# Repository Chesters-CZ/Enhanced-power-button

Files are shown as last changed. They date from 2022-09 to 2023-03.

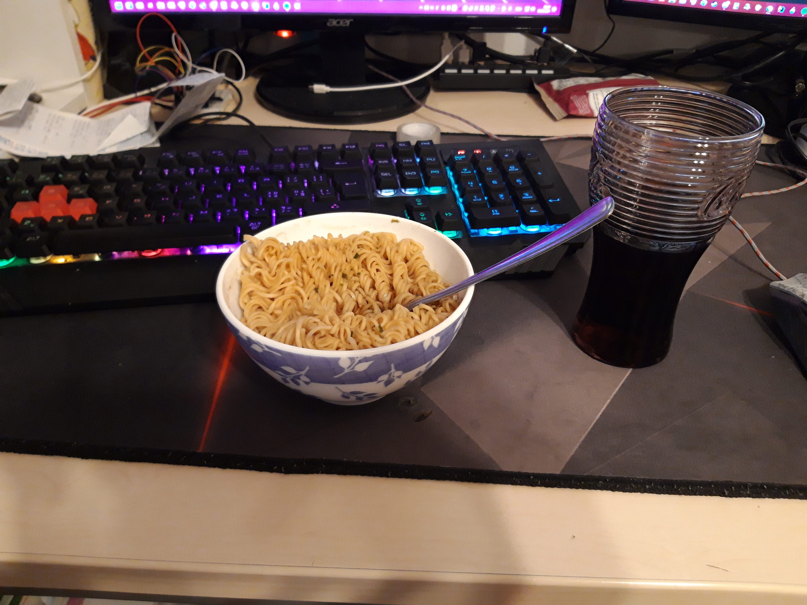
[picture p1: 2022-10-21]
fotky a schémata/concept art/20211015_182709 (1).jpg

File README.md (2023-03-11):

## Enhanced-power-button

Have you ever noticed how boring starting your computer is? You just press a button and that's it, but don't worry. I'm here to help!

# Introducing the triple Arduino setup



*this is an old picture, the final build is still a work-in-progress*

### The main Arduino

The main Arduino is the screen module. It turns on the PC via a long cable connected to the motherboard's `PWR+` and `PWR-` pins. This is triggered by the user pressing a button. The two secondary Arduinos are connected to this one, so that the screen can display popups depending on the current status of the setup. It also communicates with the python script on the computer.

### The audio module

The first secondary Arduino is the audio module. This one plays a random audio file from the connected micro SD card when the PC is turned on. If there's an error during initialization, it transmits the error code via morse code through the speaker. 

### The keycard modules

The third Arduino reads an encrypted string from a MIFARE keycard, which is decrypted using a key hardcoded on the Arduino. The decrypted string is then sent to the computer as keyboard input localized for the default Czech QWERTZ keyboard layout. If the user has chosen so when writing to the keycard, the arduino can lock the connected PC using the `Win+L` button combo. 
There is also an uploader version, which encrypts a set string and writes it onto keycards. The user chooses whether to lock the PC on removal before writing to each of the keycards.

### The python script

This is a script designed to be run on OS startup. On Windows, this can be accomplished by creating a shortcut to the .py file in `C:\Users\YourName\AppData\Roaming\Microsoft\Windows\Start Menu\Programs\Startup`. It contacts all of the Arduinos through their respective COM ports, restarting them in the process. The script then loads a config file from the user's folder in `C:\Users\` and tells the main Arduino what to display when idle. If the user has chosen time or date to be displayed, the script also sends the current time and possibly the date. The Arduino is not able to keep time information through a reboot, only keeping track of how long it is running and even that deviates by around -120s per 24h. By refreshing the time information every time the computer is rebooted, I can ignore dealing with leap years and daylight savings time by just making the user restart their computer or relaunch the script.

#### NOTE: If you're getting an error about a missing Serial module, run `pip install pyserial`. The library I used for serial communication is not installed by default.

#### NOTE 2: I could only upload a compressed version of the final pdf. The original version is available on my website [here](https://chesters.cz/files/Maturitni-prace.pdf).

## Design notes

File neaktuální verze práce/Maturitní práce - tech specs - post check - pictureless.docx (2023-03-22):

MATURITNÍ PRÁCE

Obohacené zapínací tlačítko se zabezpečovací funkcionalitou

Studijní obor: IT

Třída: C4

Školní rok: 2022/2023

Jméno a příjmení: Vít Bezouška

Vedoucí práce: Radek Lampíř

Abstrakt

Popis zařízení zlepšující požitek ze zapínání stolního počítače. Nabízí základní zabezpečovací funkce a možnosti přizpůsobení.

Abstract

Describing a device used to enhance the user experience of turning on one’s PC. Some basic security and customization features are included.

Klíčová slova

Arduino, hardware, periferie, C++, elektronika

Prohlašuji, že jsem tuto práci vypracoval(a) samostatně a použil(a) jsem literární prameny a informace, které cituji a uvádím v seznamu použité literatury a zdrojů informací.

V Praze dne …………. ……..……………………

jméno a příjmení

Obsah

Úvod 8

Účel zařízení 9

Ochrana zapnutí počítače 9

Ochrana před fyzickými keyloggery 9

Automatické uzamčení počítače při odchodu 10

Způsob, jak zapnout počítač bez sehnutí 10

Zpříjemnění začátku pracovní doby 10

Zobrazení času nebo data 10

Limitace zařízení 11

Zapínání počítače nelze zabezpečit 11

Heslo na RFID čipu lze přepsat 11

Přeprogramovatelnost Arduin 11

Použité materiály 12

Popis jednotlivých součástek 13

Arduino Nano 13

Jak se s Arduinem pracuje? 13

Co je COM port? 13

Arduino Leonardo 14

Breadboardy 15

Jednopinové spoje 15

LCD displej 15

Reproduktor 16

Červené tlačítko s krytkou 16

Páčkový přepínač 16

Čtečka micro SD karet a karta samotná 16

PNP tranzistor 17

680KΩ rezistor 17

Drát do počítače a zpět 17

Spínač na zámek 17

LED diody 17

RFID-RC522 a MIFARE čip 18

Dvojitý terminál 18

Malé šroubky 18

Použitý software 19

Word 19

Arduino IDE 19

Programování Arduin v Arduino IDE 19

PyCharm Professional 23

GIMP 23

image2cpp 23

Audacity 24

GitHub 24

FontConvert 24

Tinkercad 25

Draw.io 25

Použité knihovny 26

Adafruit GFX a SSD1306 26

TMRpcm 26

SpaniakosAES 26

Implementace base64 26

CzechKeyboard 26

Easy MFRC522 26

Popis jednotlivých modulů 27

Obrazovkový modul 27

Popis fungování 27

setup() 27

loop() 28

Uživatel nemačká tlačítko 28

Uživatel mačká tlačítko 28

Audio modul je připraven 29

Audio modul není připraven 29

Audio modul 29

Popis fungování 29

setup() 29

loop() 30

RFID moduly 30

Zapisovací (šifrovací) modul 30

Popis fungování 31

setup() 31

loop() 31

Čtecí (dešifrovací) modul 32

Popis fungování 32

setup() 32

loop() 32

Šasí 34

Základ krabičky 34

Stropní panel 35

Boční panel 35

Závěr 36

Seznam použitých zdrojů 37

Slovník pojmů 38

# Úvod

Tato práce popisuje mnou navržené a vytvořené zabezpečovací zařízení pro stolní počítač a jeho vlastnosti.

Funkcionalita je rozdělená mezi tři mikrokontrolery Arduino, konkrétně dva modely Nano a jeden model Leonardo. Jedno Nano ovládá displej, zapíná počítač a komunikuje s pythonovým scriptem. Toto Nano a k němu připojené periferie budu nazývat displejovým nebo obrazovkovým modulem. Druhé z Nan na povel displejového modulu přečte z micro SD karty audio soubor a přehraje ho. Nazývejme jej zvukovým modulem. Úkolem Arduina Leonardo je přečíst zašifrované heslo z přiloženého RFID čipu nebo karty, dešifrovat ho, a následně ho poslat jako klávesnicový vstup do počítače. To je modul čipový.

Zabezpečení samotné je zajišťováno třemi funkcemi. Zařízení zaprvé omezuje přístup k napájecímu tlačítku počítače nepovolaným osobám tak, aby nemohly počítač vypnout ani zapnout. Zadruhé pracuje jako password manager hesel uložených na RFID čipu či kartě. Poslední funkcí je možnost nastavení automatického odhlášení z uživatelského profilu v systému Windows po odejmutí čipu či karty ze čtecího senzoru.

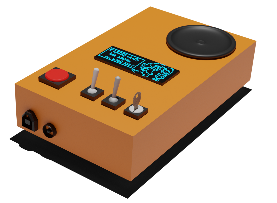
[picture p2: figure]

Součástí práce bylo navrhování a sestavování hardwarových obvodů, navrhování 3D tištěného šasí, programování mikrokontrolerů Arduino v C++ a vytváření pythonového scriptu, který zprostředkovává komunikaci mezi počítačem a jedním z Arduin.

SEQ Obrázek \* ARABIC 1 První vizualizace toho, jak by mohla vypadat finální podoba zařízení

# Účel zařízení

Hlavním cílem tohoto modulu je pomoct i laickému uživateli zabezpečit jeho počítač před těmi nejobecnějšími kyberhrozbami a navíc trochu zpříjemnit jeho používání.

## Ochrana zapnutí počítače

Spínač na klíč funguje jako prevence neoprávněného zapnutí. Tento způsob ochrany je sice velmi jednoduchý, ale nelze ho obejít, aniž by byly zanechány známky vniknutí. Stačí na šroubky na krabičce a od počítače nalepit bezpečnostní nálepky. Když se uživatel vrátí k počítači a uvidí, že se do něj někdo pokoušel dostat, může si okamžitě změnit hesla a zabránit tak neoprávněnému přístupu do svých účtů.

SEQ Obrázek \* ARABIC 2 Příklad použití bezpečnostní nálepky k zabezpečení krabičky čokoládových bonbónů

## Ochrana před fyzickými keyloggery

Keylogger je zařízení, které si zapamatovává uživatelské vstupy aniž by je blokovalo a je schopno je poté poskytnout útočníkovi, který z nich může vyčíst citlivé údaje. Proti digitálním keyloggerům se lze bránit pomocí aktuálního antivirového programu. Existují ale také fyzické keyloggery, malá zařízení se dvěma USB porty. Do jednoho se připojí zařízení, které bude odposloucháváno a ten druhý se připojí do počítače. Zařízení si všechny vstupy ukládá do interního úložiště, nebo je přeposílá dál přes wifi.[1]

Přestože průměrný keylogger stojí okolo 1500Kč, začínají se s nimi setkávat i učitelé na základních školách. Dají se totiž objednat na dobírku přes internet. Děti jimi pak získávají přihlašovací údaje učitelů, které následně zneužívají.[2] Správné použití mého zařízení tohle může přinejmenším velmi ztížit.

Používá totiž čtečku MIFARE RFID karet, ze kterých přečte zašifrované heslo, sám si ho dešifruje a výsledek pošle do počítače jako klávesnicový vstup. Je tedy také zranitelný vůči tomuto útoku. Když se ale zkombinují tyto dva způsoby zadávání hesla, může to útočníkovi ztížit získávání hesla. Například když klávesnicí uživatel zadá hes, mým modulem lo, a klávesnicí ještě 123, útočníkovi se zobrazí hes123 a lo odděleně a bude pro něj těžší získat tu správnou kombinaci.

## Automatické uzamčení počítače při odchodu

Na čipovou kartu, na které je uložené zašifrované heslo, lze také nahrát informaci o tom, zda má RFID modul po odebrání karty ze čtečky zamknout počítač. Kdyby se pak čipová karta používala i třeba k odemknutí dveří toalety, musel by si ji uživatel vzít s sebou, a jeho počítač by pak nezůstal odemčený a zneužitelný.

## Způsob, jak zapnout počítač bez sehnutí

Umístí-li si uživatel modul na stůl, nebude se muset shýbat k zemi, aby si zapnul počítač.

## Zpříjemnění začátku pracovní doby

Modul po spuštění počítače přehraje náhodný zvuk z připojené micro SD karty. Uživatel si na ní může nahrát své oblíbené písničky a zlepšit si náladu ještě než se pustí do práce.

## Zobrazení času nebo data

Podle toho, co si uživatel zvolí, se na displeji může při nečinnosti zobrazovat buď aktuální datum, nebo čas. Nastavení data a času se aktualizuje na systémové hodnoty při každém spuštění počítače, není tedy třeba modul přenastavovat každých půl roku.

# Limitace zařízení

Toto zařízení není perfektní a má jisté nedostatky. Považujme ho za proof of concept, ne jako finální produkt. Mnoho těchto chyb je totiž způsobeno limitacemi, které není realistické řešit v mém socioekonomickém postavení.

## Zapínání počítače nelze zabezpečit

Dokud se budou počítače zapínat pomocí zkratování dvou pinů, nebude možné jej efektivně ochránit před neoprávněnými osobami. Vždy totiž bude možné nějakým způsobem obnažit kontakty a zkratovat je.

Tohle by se dalo vyřešit spoluprací s výrobci základních desek. Kdyby totiž základní deska reagovala pouze na zaslání nějakého relativně unikátního kódu, šlo by moje zařízení vybavit zabezpečovacím čipem, který by se základní deskou komunikoval a takovýto kód poskytl.

Mohlo by se jednat o hardwarový bezpečnostní token, který by si se zapnutým počítačem vyměňoval seedy ke generování klíčů. Vypnutý počítač by pak požadoval kód, který by hardwarový token vygeneroval třeba z několika posledních seedů a aktuálního času. Útočník by potom neměl jak počítač zapnout.

## Heslo na RFID čipu lze přepsat

Jelikož jsou data zapsaná na čipy, užívané v tomto projektu, přepsatelná, útočník by je teoreticky mohl změnit anebo smazat. Ideálně by se používaly čipy s pamětí WORM. Při změně hesla nebo šifrovacího klíče by pak ale bylo nutné vydat uživateli nový čip.

## Přeprogramovatelnost Arduin

Mikrokontrolery, které používám jsou jednoduše přeprogramovatelné. Stačí je připojit k počítači a nahrát do nich jiný kód. Tento nedostatek by se dal vyřešit využitím vlastních designů mikrokontrolerů s WORM pamětí.

# Použité materiály

Na každý projekt je potřeba trocha hardwaru. Zde je seznam toho, co bylo použito na tento projekt.

Počet | Součástka
2 | Arduino Nano
1 | Arduino Leonardo
1 | Breadboard malý
2 | Breadboard velký
>50 | Jednopinový spoj
1 | IIC LCD displej 128x32px, jednobarevný
1 | Reproduktor 2W 8Ω
1 | Velké červené tlačítko
1 | Odklápěcí kryt na velké červené tlačítko
3 | Páčkový přepínač
1 | Micro SD modul
1 | Micro SD karta
4 | PNP tranzistor
1 | Malý 680kΩ rezistor
2 | Kabel, který dosáhne od krabičky k PW pinům
1 | Spínač na zámek (s klíčkem)
4 | Libovolná LED dioda
1 | RFID modul RC-522
1 | MIFARE Classic čip
1 | Šroubovací terminál na dva drátky
12 | Šroubků 2x10mm

# Popis jednotlivých součástek

Důležité je vědět nejen co použít, ale i jak to použít.

## Arduino Nano

Nejstarší model Arduina, který se dnes běžně používá. Arduino je vlastně jen veřejně dostupná technická specifikace, podle které si kdokoliv může nechat vytvořit své vlastní Arduino. Arduina, která já používám v tomto projektu nejsou originální, jde o verzi z Číny za zlomek ceny. Pořád ale mají naprosto identickou funkcionalitu jako kdybych si koupil originální Genuino, a protože se prodejce nesnažil tvrdit, že by šlo o oficiální výrobek, je toto Arduino naprosto legální.[3]

SEQ Obrázek \* ARABIC 3 Arduino Nano

Arduino Nano v sobě má mikrokontroler ATmega328 o frekvenci 16 MHz a samo o sobě spotřebovává zhruba 20 mA při 5V DC. Tato spotřeba se samozřejmě zvyšuje, když k němu připojíme nějakou periferii. Každý z jeho 22 I/O pinů totiž dokáže poskytnout až 40 mA. Arduino ale nemusíme napájet přes USB port. Někdy může být vhodnější mít samostatnou baterii, ke které Arduino rovnou připojíme. V takovém případě by baterie měla mít napětí mezi 7 a 12V DC. Co se týče úložiště, má Nano k dispozici zhruba 30KB flash paměti z celkových 32, ty 2KB zabírá bootloader. Operační paměť Arduina má kapacitu 2KB.

### Jak se s Arduinem pracuje?

Arduino Nano se k počítači připojuje do USB portu počítače pomocí mini USB kabelu. Počítači se ohlásí jako zařízení připojené přes emulovaný COM port.

#### Co je COM port?

COM porty byly sériové porty, které se dříve používaly k připojení tiskáren, obrazovek a dalších periferií v dobách před USB.

SEQ Obrázek \* ARABIC 4 Konektor DE-9 přes který původně probíhala komunikace COM (volné dílo)

Dnes už na počítačích tyto porty fyzicky nenajdeme, ale některé periferie si i tak vyžádají, aby jim byl přidělen virtuální COM port, protože jinak komunikovat neumí. Operační systém tedy „vytvoří“ nový COM port, který těmto zařízením přiřadí. Ten nový port sice fyzicky neexistuje, ale programy, ani připojená zařízení rozdíl nepoznají.

Proč se ale tato stará technologie pořád používá? Hlavním důvodem je, že implementace komunikace přes COM je relativně nenáročná a může probíhat i se zařízeními připojenými přes běžné USB.

Nevýhodou tohoto způsobu komunikace je velmi nízká propustnost dat, ta se pohybuje v jednotkách až desítkách kilobitů za sekundu,[4] ale zařízení, která COM využívají, nepotřebují, aby komunikace byla rychlá. Naprosto jim stačí, že nějaká vůbec je, protože by vyšší rychlosti buď nestíhala, anebo neposílají tak velké objemy dat, aby vyšší propustnost měla nějaký znatelný dopad.

## Arduino Leonardo

SEQ Obrázek \* ARABIC 5 Arduino Leonardo

Arduino Leonardo si lze představit jako větší a lepší Arduino Nano. Má o 500B větší operační paměť, pohání ho mikrokontroler ATmega32u4 a napájet ho lze 6 až 20V DC. Navíc nepotřebujeme breadboard, abychom do něj něco zapojili, drátky můžeme rovnou strkat do jeho zdířek.

Jeho hlavní výhodou je ale schopnost posílat do počítače klávesnicové vstupy a to bez použití jiných kabelů, než micro USB, kterým ho napájíme. Můžeme pomocí něj tedy ulehčit uživatelovi práci a například za něj napsat heslo, nebo pomocí klávesové zkratky Win + L zamknout jeho počítač, pokud detekuje jeho nepřítomnost.

## Breadboardy

Breadboard je destička, pomocí které se dají navrhovat a testovat obvody bez pájení. Sloty v breadboardu jsou spojené do řádků, kraje velkých breadboardů pak do sloupců. Dovolují vývojářům a kutilům zastrčit do nich součástky, vyzkoušet funkcionalitu, a pak součástky zase vyndat a použít znovu. Breadboardy mívají na stranách zářezy anebo výstupky, aby se daly spojit pro jednodušší práci.

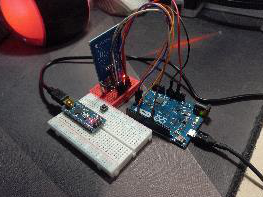
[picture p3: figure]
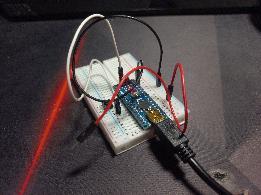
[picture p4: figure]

SEQ Obrázek \* ARABIC 6 Příklad použití breadboardů

## Jednopinové spoje

Drátky kompatibilní s breadboardy a jinými součástkami. Dají se pořídit v jakékoliv kombinaci konektorových pohlaví.

## LCD displej

SEQ Obrázek \* ARABIC 7 Přiklad použití jednopinových spojů

LCD displej, který používám má rozlišení 128x32 pixelů. Umí zobrazovat jen jednu barvu, a to světle modrou. Komunikuje s Arduinem pomocí protokolu IIC. Lze na něm zobrazovat jednotlivé pixely, čáry, obrazce, anebo rovnou obrázky, či text s vlastním fontem. Víc o zobrazování obrázků anebo používání vlastních fontů najdete v sekci použitý software.

SEQ Obrázek \* ARABIC 8 Příklad použití displeje k zobrazení mého pseudonymu při startu obrazovkového modulu

## Reproduktor

Reproduktor, který používám má výkon 2W a impedancí 8Ω. Výborně reprodukují vysoké frekvence, u těch nižších jsou tišší a reprodukovaný zvuk je méně kvalitní. Kvalita přehrávaného audia je ale také limitována přehrávacími schopnostmi Arduina, které dokáže z SD karty přehrát audio maximálně o 8 bitové hloubce a vzorkovací frekvenci 16kHz.

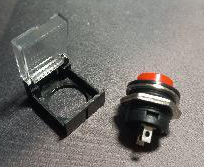
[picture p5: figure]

SEQ Obrázek \* ARABIC 9 Reproduktor s připájenými konektory

SEQ Obrázek \* ARABIC 10 Tlačítko a kryt.

## Červené tlačítko s krytkou

Tlačítko se bez matice vloží do krytky a matice se pak nandá na závit tlačítka. Krytka pak pevně drží a chrání tlačítko před nechtěným použitím.

## Páčkový přepínač

Běžný přepínač s nevšedním vzhledem. Jeden dokáže přepínat dva oddělené obvody zároveň. Upevňovací mechanismus se silně podobá tomu u červeného tlačítka.

## Čtečka micro SD karet a karta samotná

SEQ Obrázek \* ARABIC 12 Dva přepínače

Jeden z mála modulů, který je napájen 3.3V místo 5V. To ale problém není, Arduina mají i třívoltový výstup. Co se týče kapacity micro SD karty, úplně by stačilo 64MB. Audio soubory, které jsou na ní uložené jsou totiž velmi jednoduchého formátu, aby je Arduino stíhalo přehrát. Datový tok těchto souborů nepřevyšuje 8KB/s a jejich velikost je tedy velmi malá.

SEQ Obrázek \* ARABIC 11 Čtečka micro SD karet a 128MB micro SD karta

## PNP tranzistor

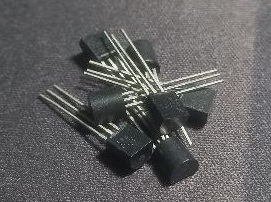
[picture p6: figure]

SEQ Obrázek \* ARABIC 17 Několik tranzistorů

SEQ Obrázek \* ARABIC 16 Pás rezistorů. Jeden chybí, ten už byl použit.

SEQ Obrázek \* ARABIC 15 Zhruba 25m červeného kabelu

SEQ Obrázek \* ARABIC 14 Spínač s dvěma klíčky

SEQ Obrázek \* ARABIC 13 Několik svítících diod

PNP tranzistory jsou něco jako velmi jednoduchý programovací if. Propouští proud z emitoru do kolektoru jenom když je napětí v bázi zhruba o půl voltu nižší než v emitoru.

## 680KΩ rezistor

Bez pulldown odporu na lince signálu z obrazovkového do zvukového modulu se stávalo, že zvukový modul začal sám o sobě hrát. U jiných modulů se tohle zatím nestalo.

## Drát do počítače a zpět

Protože napětí i proud, který drátem bude procházet, je nízký, na volbě drátu skoro vůbec nezáleží. Drát, který jsem použil já, byl červený CYA 1, nejlevnější druh prodávaný po metrech, vhodný víceméně na všechny nízkonapěťové účely.

## Spínač na zámek

Stejně jako většinu visacích zámků lze i tento jednoduše obejít, ale šlo mi spíš o estetickou hodnotu. Je to další vychytávka, která zaujme hlavně kutily.

## LED diody

Elektroluminiscenční diody jsou jeden z nejefektivnějších způsobů konverze elektrické energie na světlo. Navíc jsou levné a jednoduché k použití.

## RFID-RC522 a MIFARE čip

Pomocí tohoto modulu lze zapisovat i číst z kompatibilních čipů a čipových karet MIFARE CLASSIC.

## Dvojitý terminál

SEQ Obrázek \* ARABIC 18 RFID modul i s čipem a čipovou kartou

Takovýto šroubovací terminál je nejjednodušší a nejspolehlivější způsob, jak připojit něco k Arduinu kabelem. Šroubek se vyšroubuje a do slotu se vloží obnažený kabel nebo drát. Šroubek se zase zašroubuje a kabel se přiskřípne mezi konektory. I přes mírná škubání a popotahování je pak kabel dobře připojen.

SEQ Obrázek \* ARABIC 19 Jeden slot terminálu je volný, v druhém slotu pevně připojený kabel

## Malé šroubky

SEQ Obrázek \* ARABIC 20 Krabička šroubků

Těmito šroubky jsem přišrouboval k sobě části 3D tištěné krabičky na finální produkt. Akorát se také vejdou do zdířek v Arduinu Leonardo, takže je relativně jednoduché ho připevnit ke stropu krabičky.

# Použitý software

## Word

K psaní této práce byl použit Microsoft Word, konkrétně Word 2019.

## Arduino IDE

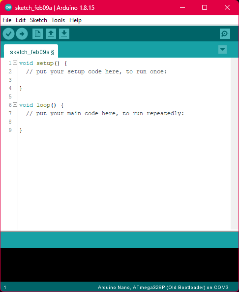
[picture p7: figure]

Integrované vývojové prostředí, neboli IDE je program určení k psaní dalších programů. IDE většinou podporují jen některé programovací jazyky, nebo jen některé platformy. K vývoji programů na Arduino potřebujeme takové IDE, které by nám dovolilo nejen napsat program v C++, ale i ho bezbolestně nahrát do Arduina.

Prázdný projekt v Arduino IDE

Jedno takové vyvinuli sami tvůrci Arduina. Nenabízí sice našeptávání, či jiné pokročilé funkce, ale jednoduše se přes něj nahrávají programy na Arduina. Stáhnout se dá na https://www.arduino.cc/en/software.

SEQ Obrázek \* ARABIC 22 Připojené Arduino Nano

### Programování Arduin v Arduino IDE

Po instalaci IDE je nutné ještě připojit samotné Arduino k počítači. Každý model má nějaký USB port, přes který ho lze jednoduše připojit. Starší modely mívají mini USB, novější mají micro USB a ty nejnovější podporují USB C.

Spusťme Arduino IDE. Objeví se nám šablona nového projektu s dvěma metodami, setup() a loop(). Jak napovídají komentáře, kód v metodě setup() se spustí jednou při startu Arduina a metoda loop() se bude volat donekonečna.

Arduino se programuje v C++. Chceme-li například, aby Arduino po zapnutí rozsvítilo LED diodu, kterou má v sobě zakomponovanou, vložíme do metody setup() následující kód:

pinMode(LED_BUILTIN, OUTPUT);
digitalWrite(LED_BUILTIN, HIGH);

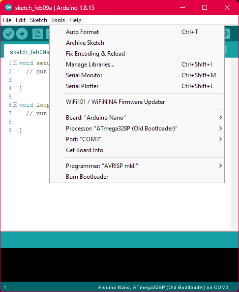
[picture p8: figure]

Tím Arduinu řekneme, že pin LED_BUILTIN bude výstupní a že do něj chceme zapsat hodnotu HIGH, čili pustit do něj proud.

Chceme-li do Arduina kód zapsat, musíme nejdříve IDE říct, co máme za Arduino a přes který COM port s ním má komunikovat. To nastavíme v dropdown menu Tools na horní liště okna. Jakmile si navolíte správné nastavení, můžete kliknout na ikonku šipky vlevo nahoře. Tím dáte IDE povel zkompilovat a poslat program do Arduina.

Rozbalené menu Tools

Pokud jste zvolili správná nastavení, mělo by se Arduino rozblikat a pak by mělo rozsvítit dvě ze svých diod. Jedna indikuje zapnutí a tu druhou jste zapnuli programem.

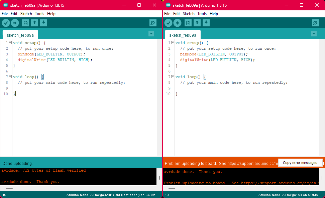
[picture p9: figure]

SEQ Obrázek \* ARABIC 24 Výsledek úspěšného a neúspěšného pokusu o nahrání programu

Vyskočila-li chybová hláška, většinou je problém v nastavení v Tools. Zkontrolujte volbu Arduina a procesoru a zkuste to znovu.

Pokud se vám v konzolovém výstupu IDE objevila chybová hláška, není třeba panikařit. Pravděpodobně je chyba někde v nastavení v Tools. Vraťte se tam a zkuste jiná nastavení.

Kdybyste chtěli, aby dioda po zmáčknutí tlačítka zhasla, můžete do setup() přidat ještě:

pinMode(3, INPUT_PULLUP);

Čímž řeknete Arduinu, že pin D3 bude vstupní a dokud ho nespojíte s jedním z uzemňovacích GND pinů, tak z něj Arduino vyčte hodnotu HIGH. Do loop() pak přidejte ještě

if (digitalRead(3) == LOW){
digitalWrite(LED_BUILTIN, LOW);
}

Potom jeden pin tlačítka spojte s D3 a druhý s GND. Dokud nezmáčknete tlačítko, dioda bude svítit, ale jakmile ho zmáčknete, dioda zhasne.

SEQ Obrázek \* ARABIC 26 Tlačítko nezmáčknuto, dioda svítí

SEQ Obrázek \* ARABIC 25 Tlačítko zmáčknuto, dioda přestala svítit

Nemusíme ale všechno programovat sami. Arduino IDE také obsahuje ukázky. V dropdown menu File v horní liště okna je můžeme najít pod volbou Examples. Ukázky mohou pocházet jak od tvůrců Arduina, tak od developerů různých knihoven.

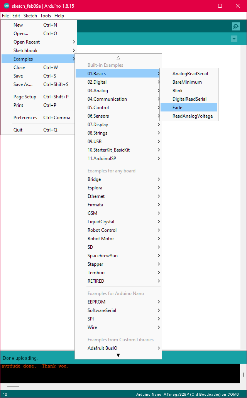
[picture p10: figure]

Podívejme se třeba, jak se podle tvůrců Arduina dělá, aby LED dioda postupně zhasínala a zase se rozsvěcela. Najděte v Examples položku 01.Basics, a v ní najděte Fade. Po rozkliknutí se vám načte už hotový projekt.

Cesta nabídkami k ukázce Fade

Tyto projekty jsou většinou velmi dobře okomentované, aby se z nich dalo jednoduše vyčíst, která část co dělá.

Podívejme se tedy na kód, můžeme z něj vyčíst, že program bude do pinu 9 velmi rychle střídavě posílat a neposílat proud v poměru, který se každých 30ms zvýší o 5/255 , dokud nebude na 255/255 . Jakmile této hodnoty dosáhne, bude zase poměr postupně snižovat dokud nedosáhne nuly. Když k pinu 9 připojíme LED diodu, uvidíme ji postupně zhasínat a zase se rozsvěcet. Tím jsme měli možnost zjistit nejen jak funguje PWM, ale i jak ho v projektu použít.[5]

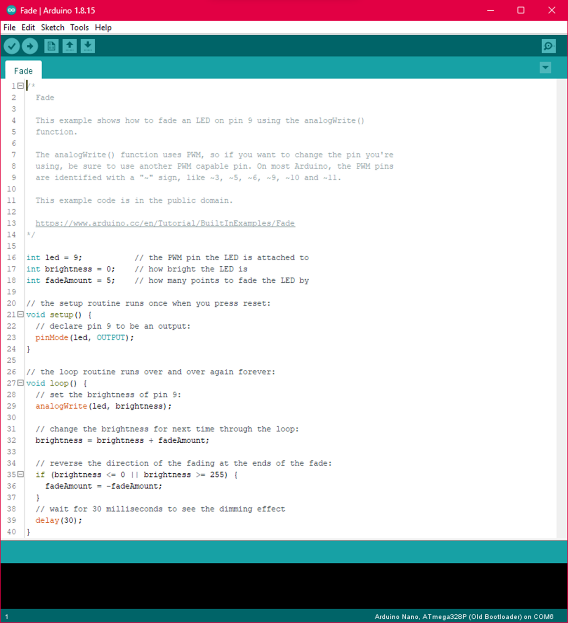
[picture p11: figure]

Ukázka Fade v Arduino IDE

## PyCharm Professional

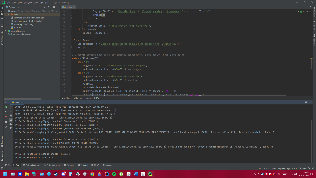
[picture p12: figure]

PyCharm je IDE vytvořené speciálně pro práci s Pythonem. Vyvinula jej česká společnost JetBrains, která je mimochodem také zodpovědná za vytvoření programovacího jazyka Kotlin, což je nadstavba na Javu.

Práce v prostředí PyCharm

PyCharm jako takový má dvě varianty, Community Edition, která je zdarma a open-source, a Professional Edition, která je placená a proprietární. Liší se hlavně v pokročilých funkcích jako podpora databází a SQL, která chybí v bezplatné edici. Jako student ale mám k dispozici edici Professional zdarma.

## GIMP

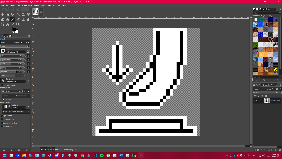
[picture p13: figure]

Program k manipulaci s obrázky pod licencí GNU je freewarová imitace Photoshopu. Využil jsem jej hlavně k tvorbě pixel artu, který jsem pak zobrazoval na displeji obrazovkového modulu.

Práce s GIMPem

Abych redukoval množství informací, které se musí na Arduino vejít, vytvořil jsem vždy nejprve návrh jak bude nějaká scéna či animace vypadat a poté jsem ji rozdělil na jednotlivé komponenty a ty teprve nahrál na Arduino.

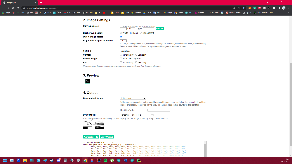
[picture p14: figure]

## image2cpp

I2CPP je jednoduchá webová aplikace, která je schopná konvertovat obrázek na bytecode, se kterým je Arduino schopno pracovat. Umí ale fungovat i obráceně, tzn. z bytecodu udělat obrázek.

Konverze malé bitmapy na kód.

Bez tohoto programu bych musel buď všechny obrázky přepisovat na bytecode ručně, anebo se obejít bez nich.

## Audacity

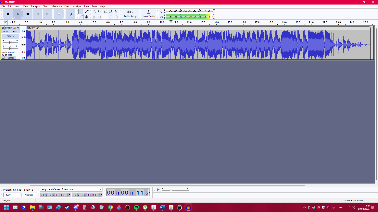
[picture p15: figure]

Audacity je freewarový program, pomocí kterého jsem překodekovával zvukové soubory pro audio modul. Arduino totiž nemá dost rychlé CPU, aby zvládlo v reálném čase přečíst a dekomprimovat příliš náročný audio soubor.

STARTU46.WAV otevřený v Audacity

Bohužel se při zjednodušování audia pro Arduino výrazně zhorší kvalita zvuku. Snímkovací frekvence se musí snížit na 8kHz a ukládat se mohou jen osmibitové hodnoty. To znamená, že poloha membrány reproduktoru se může změnit maximálně 8 000x za sekundu a to na jednu z 256 poloh, takže nelze reproduktor ovládat tak jemně, jak by bylo potřeba. Například zvuk ukládaný na CD má standardně snímkovací frekvenci 44.1kHz a 16bitovou hloubku.

Na druhou stranu reproduktor, který používám, sám zvuk zkresluje, takže i s vysokou kvalitou zdrojového audia by to neznělo o moc lépe.

Repozitář tohoto projektu na GitHubu

## GitHub

GitHub je společnost, u které si můžete vytvořit libovolný počet programovacích projektů, tzv. repozitářů, a poté do nich v balících posílat změny v kódu. Všechny iterace kódu jsou uloženy a lze se jednoduše vrátit k jakékoliv verzi.

Práce s FontConvertem v Terminálu Windows

## FontConvert

FontConvert je jednoduchý konzolový program, který ze souboru s fonty přečte, jak jednotlivé znaky vypadají, a pak je konvertuje na bitmapy, které uloží ve formátu kompatibilním s grafickými knihovnami na Arduino.

## Tinkercad

Další webová aplikace, ale tentokrát na design 3D tištěného šasí na všechny 3 moduly. Dovoluje pracovat v reálných rozměrech a následně exportovat do formátů, které podporuje většina slicerů.

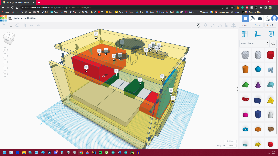
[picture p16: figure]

Model včetně komentářů a pomocných bloků v prostředí Tinkercad

## Draw.io

Rozpracované schéma obrazovkového modulu

Draw.io je bezplatná webová aplikace, která se dá stáhnout i jako lokální. Výborně se v ní dělají profesionálně vypadající schémata a flowcharty.

# Použité knihovny

Knihovny vytvořené vývojáři Arduin nebo programovacího jazyku, který používám zde nezmiňuji.

### Adafruit GFX a SSD1306

Tyto knihovny se starají o vykreslování grafiky a následnou komunikaci s displejem. Vyvinula je společnost Adafruit Industries, LLC, která designuje, vyrábí a prodává různé součástky k použití s Arduiny, Raspberry Pi a dalšími mikrokontrolery.

### TMRpcm

Knihovna, která si z připojené SD karty přečte audio soubor a pokusí se ho přehrát. Jméno jejího autora je neznámé, schovává se pod pseudonymem TMRh20.

### SpaniakosAES

Implementace šifrovacího standardu AES. Podporuje všechny tři verze, AES-128, AES-192 i AES-256. Jejím autorem je řecký programátor Georgios Spanos.

### Implementace base64

Base64 je způsob, jak konvertovat binární kód do textu pomocí písmen, čísel a pár znamének. Jejím autorem je Densaugeo.

### CzechKeyboard

Upravená verze knihovny Keyboard od Arduina s upravenou konfigurací pro české keyboard layouty. Vytvořil ji Michal Altair Valášek.

### Easy MFRC522

Wrapper knihovny MFRC522, který zjednodušuje její použití. Knihovnu MFRC522 vytvořil Miguel André Balboa. Wrapper je od Pabla Sampaio.

# Popis jednotlivých modulů

V této sekci najdete detailní popis fungování všech tří modulů i pythonového scriptu.

## Obrazovkový modul

Tento modul se stará o zapínání počítače a zobrazování informací na displeji. Komunikuje také s pythonovým scriptem na počítači, aby získal aktuální datum a čas.

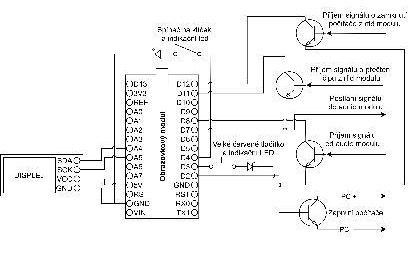
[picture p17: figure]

SEQ Obrázek \* ARABIC 37 Schéma obrazovkového modulu

Tento modul zahrnuje:

- Arduino Nano
- Displej
- 2 tranzistory
- Velké červené tlačítko

### Popis fungování

#### setup()

Arduino začne tím, že si inicializuje potřebné hodnoty a pak zobrazí hezkou animaci. Poté se pokusí přes sériovou komunikaci do počítače poslat zprávu a čeká, zda mu přijde odpověď.

Pokud ne, znamená to, že spojení s pythonovým scriptem nebylo navázáno. Arduino o tom informuje uživatele a pokračuje metodou loop().

Pokud odpověď dostane, informuje o tom uživatele a z odpovědi si přečte, co má zobrazovat na displeji při nečinnosti. Tento „spořič obrazovky“ ale doopravdy nic nešetří, jde spíš jen o využití displeje při nečinnosti. Jsou tři možnosti: odrážející se animace, která připomíná spořič obrazovky starých DVD přehrávačů, zobrazování času anebo zobrazování data.

Pokud si uživatel zvolil odrážející se animaci, Arduino nepotřebuje žádné další informace. Potvrdí přijetí zprávy a pokračuje metodou loop().

Pokud si uživatel zvolil datum nebo čas, Arduino potvrzením přijetí zprávy také zažádá počítač o informace o čase. Ty mu pythonový script pošle jako počet milisekund od půlnoci toho dne. Arduino si informaci uloží a pošle potvrzení přijetí.

Bude-li Arduino zobrazovat datum, dostane ještě informaci o datu ve formátu ISO, tzn. YYYY-MM-DD. Arduino si data zpracuje a potvrdí přijetí.

#### loop()

Arduino si nejdříve vyčistí display buffer, aby mu na displeji nezbývaly zbytky z předchozích zobrazování.

Poté zkontroluje, jestli uživatel právě mačká tlačítko.

##### Uživatel nemačká tlačítko

Arduino zkontroluje, zda od RFID modulu nepřichází nějaký signál. Pokud ano, zobrazí příslušnou hlášku spolu s ikonou. Potom pokračuje dále.

Pokud je tlačítko nezmáčknuté alespoň 100 čtecích pokusů za sebou, začne zobrazovat spořič obrazovky. Pokud to ještě nebylo 100 pokusů, zobrazí Arduino na displeji piktogram spícího Arduina, čímž uživatele informuje o blížícím se spuštění spořiče.

##### Uživatel mačká tlačítko

Arduino zkontroluje, je-li spínač na klíček odemknut. Pokud ne, zobrazí na displeji informační hlášku. Pokud ano, informuje pythonový script o statusu tlačítka, začne do počítače posílat vypínací/zapínací signál a na obrazovce ukáže piktogram prstu mačkajícího tlačítko, aby informoval uživatele o zpracování jeho akce.

Jakmile uživatel přestane tlačítko mačkat, Arduino přestane posílat do počítače signály a zkontroluje, jestli je audio modul připraven přehrát nějakou skladbu. To zjistí tak, že do něj audio modul posílá signál.

###### Audio modul je připraven

Arduino začne do audio modulu posílat signál a čeká, až to audio modul zjistí a přestane posílat signál zpátky. Do té doby zobrazuje na displeji načítací animaci.

Pokud audio modul neodpoví zhruba do tří sekund, Arduino o tom informuje uživatele přes chybovou hlášku na displeji a spustí loop() znovu.

Pokud audio modul odpoví, loop() se spustí bez chybové hlášky.

###### Audio modul není připraven

Pokud audio modul právě signál neposílá, znamená to buď že už nějakou znělku nahrává z SD karty, anebo že není zapnutý. Každopádně by povel ke spuštění písničky nezpracoval, takže Arduino žádný nepošle, ale jen oznámí uživateli proč nic nehraje.

## Audio modul

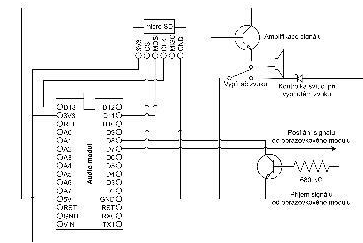
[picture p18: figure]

SEQ Obrázek \* ARABIC 38 Schéma audio modulu

Audio modul na povel obrazovkového modulu načte náhodnou skladbu z SD karty a přehraje ji.

Tento modul zahrnuje:

- Arduino Nano
- Čtečku micro SD karet
- Reproduktor
- 2 tranzistory
- Rezistor

### Popis fungování

#### setup()

Po zapnutí si Arduino ověří, že je připojená SD karta a jestli je na ní aspoň jeden audio soubor k přehrání. Pokud ano, inicializuje stavy pinů a nastaví hlasitost přehrávaného zvuku na 5, což je nejvyšší hlasitost bez zkreslení. Pokud ne, oznámí kde se stala chyba pomocí Morseovy abecedy a dále již nepokračuje.

Nebyl-li detekován problém, Arduino si načte náhodný seed, který bude používat pro generování náhodných čísel. Nakonec už jen započne komunikaci s SD kartou a přehraje z ní soubor BOOT.WAV, čímž uživatele upozorní, že je připraven.

#### loop()

Na začátku loopu Arduino začne posílat do obrazovkového modulu signál. Obrazovkový modul tím ví, že je audio modul připraven zpracovat povel. Arduino potom zkontroluje, jestli od obrazovkového modulu povel už nepřišel. Pokud ne, spustí loop() znovu.

Pokud povel přišel, Arduino potvrdí obrazovkovému modulu přijetí tím, že do něj přestane posílat signál a přijetí povelu také oznámí počítači přes sériovou komunikaci. Následně pokud nějaký zvuk už hraje, zastaví jeho přehrávání a hodí si pomyslnou n-strannou kostkou, kde n je detekovaný počet skladeb na SD kartě. Toto číslo pak vycpe nulou, je-li třeba, a dosadí ho do STARTU__.WAV. Tento soubor pak přehraje a jeho přehrání také oznámí počítači. Nutno poznamenat, že Arduino neví, jestli je reproduktor odpojen či připojen a signál do něj pouští vždy.

S dalším spuštěním metody loop() pak počká čtvrt sekundy po tom, co přestane od obrazovkového modulu dostávat signál.

## RFID moduly

Pro tento projekt je nutné buď využívat dva RFID moduly zároveň, nebo si pro nahrání dat na čipy dočasně přeprogramovat Arduino. Funkcionalita obou variant je rovnocenná, ale může být jednodušší mít k dispozici dedikovaný nahrávací modul.

### Zapisovací (šifrovací) modul

Tento modul zašifruje uložené heslo šifrovacím klíčem za použití inicializačního vektoru, zakóduje ho do base64, a zapíše na libovolný počet čipů spolu s informací, jestli po odebrání čipu zamknout počítač či ne.

Před nahráním programu na Arduino je nutné, aby uživatel upravil výchozí hodnoty v projektu na své. Šifrovaný text (heslo) může obsahovat alfanumerické znaky a symboly a musí mít délku menší než 48 znaků. Inicializační vektor může být libovolné celé číslo od 0 do zhruba 18.4 trilionů[^1][6] Šifrovací klíč se zadává jako text a může také obsahovat alfanumerické znaky a symboly. Jeho délka ale musí být přesně 16, 24 nebo 32 znaků. Délka šifrovacího klíče také určuje bezpečnost šifry, buďto AES128, AES192, nebo AES256.

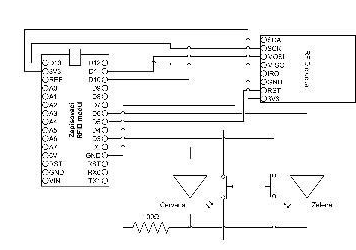
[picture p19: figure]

Tento modul zahrnuje:

- Arduino Nano
- RFID modul RC522
- 2x tlačítko
- Červená LED dioda
- Zelená LED dioda

#### Popis fungování

##### setup()

SEQ Obrázek \* ARABIC 39 Schéma šifrovacího modulu

Po zapnutí Arduino pouze naváže kontakt s počítačem, komunikuje-li, a inicializuje čtečku čipů.

##### loop()

Arduino inicializuje vstupní a výstupní piny a rozsvítí obě diody. Přes sériovou komunikaci pošle instrukce na používání; pokud chce uživatel, aby se jeho počítač po ztrátě spojení s čipem zamkl, má zmáčknout tlačítko u zelené diody, pokud ne, zmáčkne tlačítko u té červené.

Když uživatel zvolí, Arduino zhasne diodu u nezvolené volby a zkontroluje délku šifrovacího klíče. Nabývá-li délka jedné ze správných hodnot, zašifruje heslo a výsledek zakóduje do base64, aby se dalo zapsat na čip. Pak si připraví ještě délku hesla zakódovaného v base64 a zdali se má počítač vypnout po ztrátě kontaktu s čipem, a jakmile uživatel přiloží kompatibilní čip ke čtečce, tyto informace na něj zapíše a znovu spustí loop().

### Čtecí (dešifrovací) modul

Tento modul přečte zašifrované heslo z RFID čipu, pomocí přednastaveného šifrovacího klíče jej dešifruje a pošle do počítače jako klávesnicový vstup. Poté podle nastavení, které si také přečte z čipu, po odebrání čipu z dosahu čtečky buď zamkne počítač, nebo neudělá nic.

Jako u šifrovacího modulu je i tady nutné upravit program před nahráním na čip. Uživatel si ale tentokrát nemůže zvolit nový šifrovací klíč ani inicializační vektor, musí použít ty, které použil při šifrování, jinak Arduino nedešifruje heslo správně. Heslo samotné ale není třeba do tohoto modulu ukládat, Arduino ho zjistí z čipu.

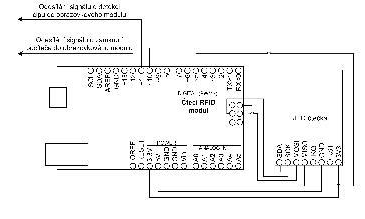
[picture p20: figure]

Tento modul zahrnuje:

- Arduino Leonardo
- RFID modul RC522

#### Popis fungování

Schéma dešifrovacího modulu

#### setup()

Po zapnutí se Arduino pokusí navázat sériovou komunikaci s počítačem a inicializuje RFID modul a klávesnicovou komunikaci.

#### loop()

Arduino zkontroluje délku šifrovacího klíče a podle ní se připraví na příslušnou úroveň šifry k dešifrování. Pak každých 50ms zkontroluje, jestli je v dosahu čtečky RFID čip. Jakmile je, počká ještě další desetinu sekundy, aby se mohl čip více přiblížit, a spojení bylo stabilnější. Poté si přečte všechny potřebné informace a dešifruje heslo, které pak pošle do počítače jako klávesnicový vstup.

Pokud bylo na čipu zapsáno, že se počítač má zamknout jakmile se čip odebere od čtečky, Arduino bude každých 100ms ukončovat a opět navazovat kontakt s čipem a bude ověřovat, že má pořád stejné ID.

Aby nedošlo ke zbytečnému vyrušení uživatele kvůli pár špatným pokusů o přečtení, povel zamknout se se počítači pošle až s desátým neúspěšným pokusem.

Povel samotný se pošle jako klávesová zkratka Win + L, která, alespoň na počítačích se systémem Windows 2000 a novějším,[7] „zamkne“ počítač, tzn. odhlásí právě přihlášeného uživatele aniž by ukončila běžící programy.

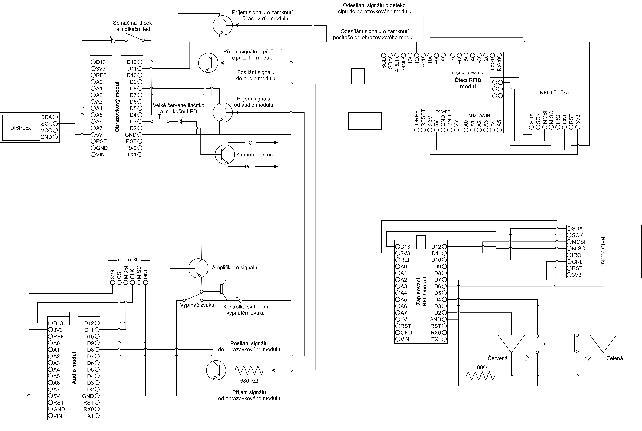
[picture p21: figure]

SEQ Obrázek \* ARABIC 41 Schéma propojených modulů

# Šasí

Tento projekt by byl relativně úplný i bez obalu, jen jako několik součástek propojených drátky. Na druhou stranu, průměrný člověk pracující v sedavém zaměstnání by si pravděpodobně na stůl nedal něco, z čeho koukají obnažené kontakty.

Navrhl jsem tedy jednoduchý 3D model krabičky, do které jsem postupně přidával díry na různé periferie a kabeláž. Byl to můj vůbec první pokus o práci s 3D tiskárnou, a tak se mnohé nepovedlo. Některé sloty byly moc blízko u sebe, jiné moc daleko a pár jich dokonce bylo moc malých.

Všechny mouchy se mi podařilo vychytat bez nutnosti cokoli tisknout znovu. Díry, které chyběly jsem provrtal, ty, které byly moc malé jsem zvětšil a ty, které byly na špatném místě jsem buď nahradil, anebo jsem se obešel bez nich.

Možná jsem se mohl pokusit model vylepšit, aby byl perfektní bez jakýchkoli modifikací hrubou silou, ale vzhledem k tomu, že 3D tisk mi zajišťoval vedoucí práce z jeho dobré vůle pomocí jeho osobní 3D tiskárny a jeho filamentu, nechtěl jsem zbytečně zneužívat jeho pohostinnost.

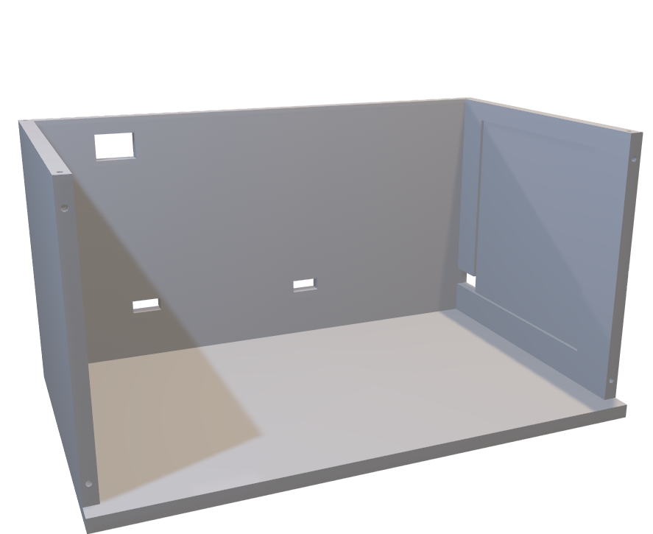
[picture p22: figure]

## Základ krabičky

Základem krabičky je kvádr bez horní a přední strany. Aby se mi projekt lépe sestavoval do krabičky, rozhodl jsem se ponechat Arduina v breadboardech a ty pouze přilepit k podlaze krabičky. Abych ušetřil trochu místa, Arduino z RFID modulu jsem připevnil na strop krabičky. Proto je také jedna z dírek tak vysoko. Tyto dírky bylo potřeba zvětšit, protože jsem při jejich návrhu nepočítal s tloušťkou celého kabelu, nýbrž jen konektorové části portu.

Šikmý pohled na základ krabičky zepředu

Tyto dírky jsou potřeba, aby bylo možné Arduina zapojit do počítače. Celkem je potřeba mít v počítači 3 volné USB-A porty, anebo si pořídit USB hub. Ta čtvrtá osamocená dírka na pravé straně je na drátky z počítače.

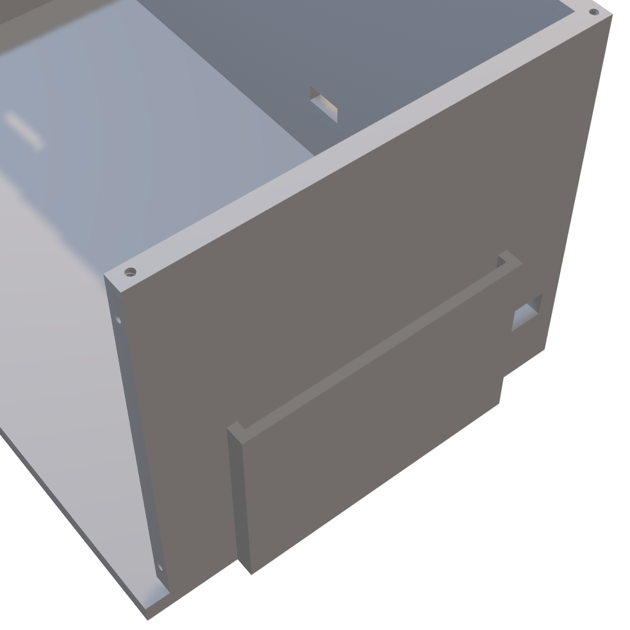
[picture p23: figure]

Vedle této dírky si také můžete všimnout ztenčené stěny. Tam jsem se snažil o lepší propustnost elektromagnetických vln. Když se totiž podíváme na tuto stranu zvenčí, najdeme tam prostor na ponechání čipové karty.

Pohled zblízka na prostor pro čipovou kartu

V rozích jsou také umístěny malé otvory na šroubky. Tyto otvory se tiskárně ale pravděpodobně nepodaří vytisknout přesněji než malý ďůlek. To ale stačí na to, aby se tam dala opřít špička šroubku. Zbytek se dá našroubovat hrubou silou.

Pohled shora na stropní panel

SEQ Obrázek \* ARABIC 45 Pohled na stropní panel zespodu

## Stropní panel

Hlavní vlastností tohoto panelu je několikero kulatých otvorů na reproduktor, tlačítko, spínač na klíček, displej, spínače a LED kontrolky. Zespoda jsou na panelu výstrupky na připevnění Arduina Leonardo z RFID modulu. Panel sám o sobě totiž není dost tlustý na to, aby šroubek neprošel skrz.

## Boční panel

Tento panel už jen zavírá krabičku a nemá na sobě žádné speciální výstupky.

Boční panel

# Závěr

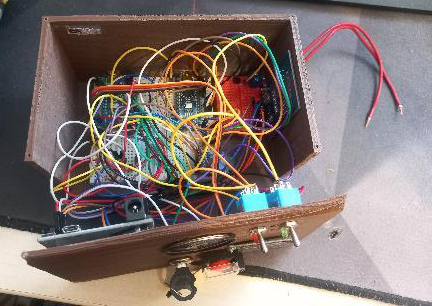
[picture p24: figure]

Tento projekt byl jako vztah. Když jsem na něm začal pracovat, bylo to něco, co jsem dělal jen tak pro radost. Sem tam jsem na něm zapracoval, ale žádné velké pokroky jsem neudělal, dokud jsem se nedozvěděl, že to s ním mohu někam dotáhnout. Jakmile mi byl uznán jako maturitní, začal jsem na něm pracovat dennodenně. Trávil jsem na něm čas a utrácel jsem kvůli němu peníze. Byly i týdny, kdy jsem na něm vůbec nepracoval, ale nakonec se mi povedlo to dotáhnout do šťastného konce.

SEQ Obrázek \* ARABIC 47 Vnitřek krabičky. Cable management nebyl součástí tohoto projektu.

Cítím, že jsem odvedl perfektní práci na něčem, co mě opravdu bavilo. Nedovedu si představit jak bych vůbec mohl tento projekt nějak zlepšit. Ani teď, ani v průběhu práce na něm.

Odnáším si z něj mnohé. Naučil jsem se programovat v C++, vytvářet modely k 3D tisku, porozumět jednoduché elektronice a jejím principům, naučil jsem se pájet a sestavovat obvody a ještě jsem mnoho dalších dovedností oprášil. Jsem toho názoru, že jsem tím dokázal nejen, že umím použít znalosti, které jsem se naučil ve škole, ale i že jsem schopen si informace dohledávat a co je potřeba i sám sebe naučit.

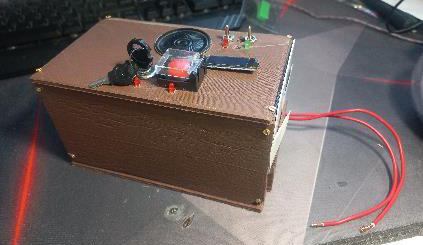
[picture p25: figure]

SEQ Obrázek \* ARABIC 48 Finální podoba tlačítka

# Seznam použitých zdrojů

[1]. Keelog. Hardware Keylogger: AirDrive & KeyGrabber Keylogger - C64 PSU Power Supply. USB keylogger hardware solutions - KeyGrabber - USB Keylogger, Wireless Keylogger, DIY Keylogger, Wi-Fi Keylogger, C64 PSU, C64 Power Supply, Commodore 64 [online]. [Wroclaw], [2004-02-05], 2023/01/31 [31.1.2023]. Veřejně přístupné na https://keelog.com
[2]. MAFRA, a.s. Děti v roli hackerů. Školy řeší případy, kdy se jim žáci nabourají do systémů - iDNES.cz. iDNES.cz – s námi víte víc [online]. Karolína Novotná (knn). MAFRA, a. s., 28. prosince 2022, [20.3.2023]. Veřejně dostupné na https://www.idnes.cz/zpravy/domaci/skolstvi-kyberneticky-utok-it.A221216_102917_domaci_knn
[3]. Arduino LLC. How to spot a counterfeit Arduino – Arduino Help Center. Arduino. [internet]. [3.2.2023]. Veřejně dostupné na https://support.arduino.cc/hc/en-us/articles/360020652100-How-to-spot-a-counterfeit-Arduino
[4]. Wikimedia Foundation, Inc. Serial port – Wikipedia. Wikipedia: The Free Encyclopedia. [online]. 26 October 2005, 1 December 2022 [31.1.2023] Veřejně dostupné z https://en.wikipedia.org/wiki/Serial_port
[5]. Arduino LLC. Arduino Reference - Arduino Reference. Arduino. [online]. [3.2.2023]. Veřejně dostupné na https://reference.arduino.cc/reference/en/
[6]. UtkarshPandey6. Maximum value of unsigned long long int in C++. In: Sandeep Jain. GeeksforGeeks. [online]. A-143, 9th Floor, Sovereign Corporate Tower, Sector-136, Noida, Uttar Pradesh – 201305: GeeksforGeeks, 03 Dec, 2020 [11.2.2023]. Veřejně dostupné na https://www.geeksforgeeks.org/maximum-value-of-unsigned-long-long-int-in-c/
[7]. Wikimedia Foundation, Inc. Windows key – Wikipedia. Wikipedia: The Free Encyclopedia. [online]. 25 April 2006, 5 January 2023 [11.2.2023] Veřejně dostupné z https://en.wikipedia.org/wiki/Windows_key

# Slovník pojmů

Termín | Význam
AES | Advanced Encryption Standard / Pokročilý šifrovací standard. Velmi rozšířený a velmi silný standard symetrického šifrování.
Alfanumerické znaky | Číslice a písmena
Arduino | Značka programovatelných mikrokontrolerů
Arduino Leonardo | Model mikrokontroleru Arduino se schopností posílat do počítače klávesnicové vstupy
Arduino Nano | Jeden z nejzákladnějších mikrokontrolerů Arduino
base64 | Způsob zapsání bytecodu jako písmena, číslice a některé znaky
báze tranzistoru | Prostřední pin tranzistoru. Pokud pustíme do báze PNP tranzistoru proud, začne téct i z kolektoru do emitoru
bezpečnostní nálepka | Nálepka, která po odloupnutí zanechá lepidlo a část potisku na povrchu na kterém byla přilepena.
Bezpečnostní token | Fyzické nebo digitální zařízení, použitelné jako náhrada hesla, nebo jako součást dvoufaktorové autentifikace. V práci je jím míněno zařízení, které ze seedu a informaci o čase vygeneruje každou minutu unikátní kód, kterým ověří svou totožnost počítači.
Bootloader | Program, který se stará o nastartování zařízení a načtení dalších instrukcí.
Buffer | Mezipaměť, do které se ukládají data, která jsou, nebo brzy budou přenášena.
Bytecode | Data, zapsaná v bytech, která jsou zpracována na počítači srozumitelný formát.
C++ | Programovací jazyk
COM port | Port přes který se připojují zařízení, která potřebují jednoduchou sériovou komunikaci.
Dropdown menu | Nabídka, která se zobrazí jako seznam možností po stisknutí tlačítka.
Emitor tranzistoru | Výstupní pin tranzistoru.
Emulace | Digitální simulace nějakého prostředí či funkce za účelem vytvoření vhodných podmínek pro spuštění programu, který by bez nich neběžel správně.
Filament | Tiskový materiál do 3D tiskárny.
Flowchart | Vizualizace postupu, diagram.
Freeware | Software dostupný bezplatně.
Genuino | Globální trademark, označující Arduina prodávaná společností Arduino LLC, která Arduina vyvíjí.
GND, ground | Záporný pól, uzemnění
I/O pin | Pin, který může být použit buď jako vstupní (input) nebo jako výstupní (output)
IDE | Program, určený k psaní kódu a vývoji dalších programů.
IIC, I2C, I²C | Způsob připojení jednoduchých lowendových zařízení k sobě.
Inicializace | Prvotní nastavení hodnot.
ISO | International Organization for Standardization / Mezinárodní organizace pro standardizaci. Organizace, která vytváří a propaguje jednotné standardy.
Java | Programovací jazyk
keylogger | Zařízení nebo program, které si zapamatovává uživatelovy vstupy.
klávesa Win | Klávesa s ikonou OS Windows, lidově windowsítko. Obecně nazývané jako meta tlačítko.
knihovna v programování | Kus softwaru, určený k použití jako součást jiného programu. Většinou jde o implementaci nějaké funkce, kterou by si vývojář jinak musel naprogramovat sám.
kolektor tranzistoru | Vstupní pin tranzistoru.
Kotlin | Programovací jazyk
kyberhrozba | Digitální hrozba
lokální aplikace | Aplikace, která je uložená na počítači na kterém běží.
metoda loop() | Kód, který se spouští pořád dokola po doběhnutí kódu v metodě setup()
metoda setup() | Kód, který se spustí jednou po zapnutí Arduina
micro SD karta | Malá paměťová karta
micro USB | Malý USB konektor. Předchůdce USB-C a nástupce mini USB. Používal se zejména ve starších zařízeních s Androidem.
MIFARE | Standard čipových karet a čteček, komunikujících přes RFID.
mini USB | Nejstarší malý USB konektor. Předchůdce micro USB. Používal se ve starých fotoaparátech, PDA a dalších periferiích.
open source | S veřejně dostupným zdrojovým kódem. Na tento kód se pořád mohou vztahovat autorská práva.
pin | Kontakt. Často jako kovový výstupek.
PNP tranzistor | Tranzistor, který pouští proud z kolektoru do emitoru, pokud teče proud i z báze do emitoru.
pohlaví konektorů | Princip většiny konektorů spočívá v tom, že se něco do něčeho zastrčí. Predominantně konkávní konektor je označován za samce a predominantně konvexní konektor je označován za samici. Původ této terminologie je v principu vnitřního oplodňování.
port | Samice konektoru, zdířka. Někdy přenesením významu také typ konektoru.
programovací if statement | Kus kódu, jehož spuštění je podmíněno.
proof of concept | Důkaz existence konceptu. Něco, co není finální produkt, ale demonstruje vlastnosti, které by mohly být v nějakém produktu využity.
PWM | Pulse Width Modulation / Pulzně šířková modulace. Způsob, jak ovládat jednoduchý komponent tím, že do něj v různých intervalech budeme střídavě pouštět a nepouštět proud.
Python | Programovací jazyk
RFID | Radio Frequency IDentification / Identifikace na radiové frekvenci. Způsob bezdrátové komunikace na velmi krátké vzdálenosti.
script | Program, který se nemusí kompilovat, aby se spustil.
seed | Číslo, pomocí kterého se dá generovat nekonečná řada pseudonáhodných čísel. Generátor náhodných čísel inicializovaný stejným seedem bude pokaždé vracet stejnou řadu čísel.
slicer | Program, pomocí kterého se konvertuje 3D model na tisková data pro 3D tiskárnu.
SQL | Jazyk, kterým se ovládají některé databázové systémy.
USB | Specifikace univerzálních konektorů a protokolů.
USB-A | První USB konektor. Nejběžněji používaný pro myši, klávesnice, flashdisky a jiné periferie běžně připojované k počítačům.
USB-C | Nejnovější USB konektor, který lze použít jako USB-A, ethernetový RJ-45, HDMI, DisplayPort, vstupní i výstupní audio jacky a 240W nabíječku zároveň. V současnosti jediný stále podporovaný USB standard.
vycpání čísla nulou | Přidání nul na začátek čísla, aby bylo dosaženo specifikované délky ve znacích. Například chci-li vycpat 16 nebo 7 na trojciferné číslo, zapíšu je jako 016 a 007.
webová aplikace | Aplikace, běžící na webové stránce.
WORM paměť | Write once, read many. Druh paměti, která nedovoluje měnit data, která jsou na ni zapsána.
zkratování | Spojení dvou kontaktů. Nemusí nutně jít o nebezpečnou situaci.
zkreslení zvuku | Nelibá úprava audiosignálu.

[^1] Jde o 64 bitový kladný integer. Jeho maximální hodnota je 2⁶⁴, což je 18 446 744 073 709 551 615.

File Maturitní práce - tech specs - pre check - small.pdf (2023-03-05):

MATURITNÍ PRÁCE

## Obohacené zapínací tlačítko se zabezpečovací funkcionalitou

Studijní obor:IT

Třída: C4

Školní rok: 2022/2023

Jméno a příjmení: Vít Bezouška

Vedoucí práce: Radek Lampíř

Abstrakt

Popis zařízení zlepšující požitek ze zapínání stolního počítače. Nabízí základní

zabezpečovací funkce a možnosti přizpůsobení.

Abstract

Describing a device used to enhance the user experience of turning on one’s PC.

Some basic security and customization features are included.

Klíčová slova

Arduino, hardware, periferie, C++, elektronika

Prohlašuji, že jsem tuto práci vypracoval(a) samostatně a použil(a) jsem literární

prameny a informace, které cituji a uvádím v seznamu použité literatury a zdrojů

informací.

V Praze dne | | |
| jméno a příjmení

## Obsah

Úvod | 9
Účel zařízení | 10
Ochrana zapnutí počítače | 10
Ochrana před fyzickými keyloggery | 10
Způsob, jak zapnout počítač bez sehnutí | 11
Zpříjemnění začátku pracovní doby | 11
Zobrazení času nebo data | 11
Limitace zařízení | 12
Zapínání počítače nelze zabezpečit | 12
Heslo na RFID čipu lze přepsat | 12
Přeprogramovatelnost Arduin | 12
Použité materiály | 13
Popis jednotlivých součástek | 14
Arduino Nano | 14
Co je COM port? | 15
Arduino Leonardo | 15
Breadboardy | 16
Jednopinové spoje | 16
LCD displej | 16
Reproduktor | 17
Červené tlačítko s krytkou | 17
Páčkový přepínač | 17
Čtečka micro SD karet a karta samotná | 17
PNP tranzistor | 18

680KΩ rezistor | 18
Drát do počítače a zpět | 18
Spínač na zámek | 18
LED diody | 18
RFID-RC522 a MIFARE čip | 19
Dvojitý terminál | 19
Malé šroubky | 19
Použitý software | 20
Word | 20
Arduino IDE | 20
PyCharm Professional | 24
GIMP | 24
image2cpp | 24
Audacity | 25
GitHub | 25
FontConvert | 25
Tinkercad | 26
Použité knihovny | 27
Adafruit GFX a SSD1306 | 27
TMRpcm | 27
SpaniakosAES | 27
Implementace base64 | 27
CzechKeyboard | 27
Easy MFRC522 | 27
Popis jednotlivých modulů | 28

Obrazovkový modul | 28
Popis fungování | 28
setup() | 28
loop() | 29
Uživatel nemačká tlačítko | 29
Uživatel mačká tlačítko | 29
Audio modul je připraven | 30
Audio modul není připraven | 30
Audio modul | 30
Popis fungování | 30
setup() | 30
loop() | 31
RFID moduly | 31
Zapisovací (šifrovací) modul | 31
Popis fungování | 32
setup() | 32
loop() | 32
Čtecí (dešifrovací) modul | 33
Popis fungování | 33
setup() | 33
loop() | 34
Šasí | 35
Základ krabičky | 35
Stropní panel | 36
Boční panel | 36

Závěr | 37

## Úvod

Tato práce popisuje mnou navržené a vytvořené zabezpečovací zařízení pro stolní

počítač a jeho vlastnosti.

Funkcionalita je rozdělená mezi tři mikrokontrolery Arduino, konkrétně dva modely

Nano a jeden model Leonardo. Jedno Nano ovládá displej, zapíná počítač a

komunikuje s pythonovým scriptem. Toto Nano a k němu připojené periferie budu

nazývat displejovým nebo obrazovkovým modulem. Druhé z Nan na povel

displejového modulu přečte z micro SD karty audio soubor a přehraje ho. Nazývejme jej zvukovým modulem. Úkolem Arduina Leonardo je přečíst zašifrované

heslo z přiloženého RFID čipu nebo karty, dešifrovat ho, a následně ho poslat jako

klávesnicový vstup do počítače. To je modul čipový.

Zabezpečení samotné je zajišťováno třemi funkcemi. Zařízení zaprvé omezuje

přístup k napájecímu tlačítku počítače nepovolaným osobám tak, aby nemohly

počítač vypnout ani zapnout. Zadruhé pracuje jako password manager hesel

uložených na RFID čipu či kartě. Poslední funkcí je možnost nastavení

automatického odhlášení z uživatelského profilu v systému Windows po odejmutí

čipu či karty ze čtecího senzoru.

Součástí práce bylo navrhování a sestavování

hardwarových obvodů, navrhování 3D tištěného

šasí, programování mikrokontrollerů Arduino

v C++ a vytváření pythonového scriptu, který

zprostředkovává komunikaci mezi počítačem a

jedním z Arduin.


1 První vizualizace toho, jak by mohla vypadat finální podoba zařízení

## Účel zařízení

Hlavním cílem tohoto modulu je pomoct i laickému uživateli zabezpečit jeho počítač

před těmi nejobecnějšími kyberhrozbami a navíc trochu zpříjemnit jeho používání.

Ochrana zapnutí počítače

Spínač | na | klíč | funguje jako | prevence

neoprávněného zapnutí. Tento způsob ochrany

je sice velmi jednoduchý, ale nelze ho obejít,

aniž by byly zanechány známky vniknutí. Stačí

na šroubky na krabičce a od počítače nalepit

bezpečnostní nálepky. Když se uživatel vrátí

k počítači a uvidí, že se do něj někdo pokoušel

dostat, může si okamžitě změnit hesla a

zabránit tak neoprávněnému přístupu do svých

účtů.

Ochrana před fyzickými keyloggery

Keylogger je zařízení, které si zapamatovává uživatelské vstupy aniž by je blokovalo

a je schopno je poté poskytnout útočníkovi, který z nich může vyčíst citlivé údaje.

Proti digitálním keyloggerům se lze bránit pomocí aktuálního antivirového programu.

Existují ale také fyzické keyloggery, malá zařízení se dvěma USB porty. Do jednoho

se připojí zařízení, které bude odposloucháváno a ten druhý se připojí do počítače.

Zařízení si všechny vstupy ukládá do interního úložiště, nebo je přeposílá dál přes wifi.¹

Můj modul má v sobě integrovanou čtečku MIFARE RFID karet, ze kterých přečte

zašifrované heslo, sám si ho dešifruje a výsledek pošle do počítače jako

klávesnicový vstup. Je tedy také zranitelný vůči tomuto útoku. Když se ale

zkombinují tyto dva způsoby zadávání hesla, může to útočníkovi ztížit získávání

1 Keelog. Hardware Keylogger: AirDrive & KeyGrabber Keylogger - C64 PSU Power Supply. USB keylogger hardware solutions - KeyGrabber - USB Keylogger, Wireless Keylogger, DIY Keylogger, Wi-Fi Keylogger, C64 PSU, C64 Power Supply, Commodore 64 [internet]. [Wroclaw], [2004-02-05], 2023/01/31 [31.1.2023]. Veřejně přístupné na keelog.com.

2 Příklad použití bezpečnostní nálepky k zabezpečení krabičky čokoládových bonbónů hesla. Například když klávesnicí uživatel zadá hes, mým modulem lo, a klávesnicí

ještě 123, útočníkovi se zobrazí hes123 a lo odděleně a bude pro něj těžší získat tu

správnou kombinaci.

Způsob, jak zapnout počítač bez sehnutí

Umístí-li si uživatel modul na stůl, nebude se muset shýbat k zemi, aby si zapnul

počítač.

Zpříjemnění začátku pracovní doby

Modul po spuštění počítače přehraje náhodný zvuk z připojené micro SD karty.

Uživatel si na ní může nahrát své oblíbené písničky a zlepšit si náladu ještě než se

pustí do práce.

Zobrazení času nebo data

Podle toho, co si uživatel zvolí, se na displeji může při nečinnosti zobrazovat buď

aktuální datum, nebo čas. Nastavení data a času se aktualizuje na systémové

hodnoty při každém spuštění počítače, není tedy třeba modul přenastavovat

každých půl roku.

## Limitace zařízení

Toto zařízení není perfektní a má jisté chyby. Považujme ho za proof of concept, ne

jako finální produkt. Mnoho těchto chyb je způsobeno limitacemi, které není

realistické řešit v mém socioekonomickém postavení.

Zapínání počítače nelze zabezpečit

Dokud se budou počítače zapínat pomocí zkratování dvou pinů, nebude možné jej

efektivně ochránit před neoprávněnými osobami. Vždy totiž bude možné nějakým

způsobem obnažit kontakty a zkratovat je.

Tohle by se dalo vyřešit spoluprací s výrobci základních desek. Kdyby totiž základní

deska reagovala pouze na zaslání nějakého relativně unikátního kódu, šlo by moje

zařízení vybavit zabezpečovacím čipem, který by se základní deskou komunikoval

a takovýto kód poskytl.

Mohlo by se jednat o hardwarový bezpečnostní token, který by si se zapnutým

počítačem vyměňoval seedy ke generování klíčů. Vypnutý počítač by pak požadoval

kód, který by hardwarový token vygeneroval třeba z několika posledních seedů a aktuálního času. Útočník by potom neměl jak počítač zapnout.

Heslo na RFID čipu lze přepsat

Jelikož jsou data zapsaná na čipy, užívané v tomto projektu, přepsatelná, útočník

by je teoreticky mohl změnit anebo smazat. Ideálně by se používaly čipy s pamětí WORM²

Přeprogramovatelnost Arduin

Mikrokontrolery, které používám jsou jednoduše přeprogramovatelné. Stačí je

připojit k počítači a nahrát do nich jiný kód. Tento nedostatek by se dal vyřešit

využitím vlastních designů mikrokontrolerů s WORM pamětí.

2 Write once, read many. Druh paměti, která nedovoluje měnit data, která jsou na ni zapsána.

## Použité materiály

Na každý projekt je potřeba trocha hardwaru. Zde je seznam toho, co bylo použito

na tento projekt.

Počet | Součástka

### 2 Arduino Nano

### 1 Arduino Leonardo

### 1 Breadboard malý

### 2 Breadboard velký

>50 Jednopinový spoj

### 1 IIC LCD displej 128x32px, jednobarevný

### 1 Reproduktor 2W 8Ω

### 1 Velké červené tlačítko

### 1 Odklápěcí kryt na velké červené tlačítko

### 3 Páčkový přepínač

### 1 Micro SD modul

### 1 Micro SD karta

### 4 PNP tranzistor

### 1 Malý 10KΩ rezistor

### 2 Kabel, který dosáhne od krabičky k PW pinům

### 1 Spínač na zámek (s klíčkem)

### 4 Libovolná LED dioda

### 1 RFID modul RC-522

### 1 MIFARE Classic čip 1 Šroubovací terminál na dva drátky

### 12 Šroubků 2x10mm

## Popis jednotlivých součástek

Důležité je vědět nejen co použít, ale i jak to použít.

Arduino Nano

Nejstarší model Arduina, který se dnes běžně

používá. Arduino je vlastně jen veřejně

dostupná technická specifikace, podle které

si kdokoliv může nechat vytvořit své vlastní

Arduino. Arduina, která já používám v tomto
projektu nejsou originální, jde o verzi z Číny


za zlomek ceny. Pořád ale mají naprosto identickou funkcionalitu jako kdybych si koupil originální Genuino,³ a protože se prodejce nesnažil tvrdit, že by šlo o oficiální

výrobek, je toto Arduino naprosto legální.⁴

Arduino Nano v sobě má mikrokontroler ATmega328 o frekvenci 16 MHz a samo o

sobě spotřebovává zhruba 20 mA při 5V DC. Tato spotřeba se samozřejmě zvyšuje, když k němu připojíme nějakou periferii. Každý z jeho 22 I/O⁵ pinů totiž dokáže

poskytnout až 40 mA. Arduino ale nemusíme napájet přes USB port. Někdy může

být vhodnější mít samostatnou baterii, ke které Arduino rovnou připojíme.

V takovém případě by baterie měla mít napětí mezi 7 a 12V DC. Co se týče úložiště,

má Nano k dispozici zhruba 30KB flash paměti z celkových 32, ty 2KB zabírá bootloader⁶
. Operační paměť Arduina má kapacitu 2KB.Jak se s Arduinem pracuje?

Arduino Nano se k počítači připojuje do USB portu počítače pomocí mini USB

kabelu. Počítači se ohlásí jako zařízení připojené přes emulovaný COM port.

3 Globální trademark, označující Arduina prodávaná společností Arduino LLC, která Arduina vyvíjí. 4 Arduino LLC. How to spot a counterfeit Arduino – Arduino Help Center. Arduino. [internet]. [3.2.2023]. Veřejně dostupné na https://support.arduino.cc/hc/en-us/articles/360020652100-How-to-spot-a-counterfeit-Arduino (https://support.arduino.cc/hc/en-us/articles/360020652100-How-to-spot-a-counterfeit-Arduino)

5
Input/Output – Vstup/Výstup. Jak budou tyto piny použity záleží na naprogramování.
6 Program, který se stará o správný start systému a načtení nahraného programu.

3 Arduino Nano

Co je COM port?

COM porty byly sériové porty, které se dříve používaly k připojení tiskáren,

obrazovek a dalších periferií v dobách před USB.

Dnes už na počítačích tyto porty fyzicky

nenajdeme, ale některé periferie si i tak vyžádají,

aby jim byl přidělen virtuální COM port, protože

jinak komunikovat neumí. Operační systém tedy

„vytvoří“ nový COM port, který těmto zařízením

přiřadí. Ten nový port sice fyzicky neexistuje, ale

programy, ani připojená zařízení rozdíl nepoznají.

Proč se ale tato stará technologie pořád používá? Hlavním důvodem je, že

implementace komunikace přes COM je relativně nenáročná a může probíhat i se

zařízeními připojenými přes běžné USB.

Nevýhodou tohoto způsobu komunikace je velmi nízká propustnost dat, ta se pohybuje v jednotkách až desítkách kilobitů za sekundu,⁷ ale zařízení, která COM

využívají, nepotřebují, aby komunikace byla rychlá. Naprosto jim stačí, že nějaká

vůbec je, protože by vyšší rychlosti buď nestíhala, anebo neposílají tak velké objemy

dat, aby vyšší propustnost měla nějaký znatelný dopad.

Arduino Leonardo

Arduino Leonardo si lze představit jako větší a

lepší Arduino Nano. Má o 500B větší operační

paměť, pohání ho mikrokontroler ATmega32u4

a napájet ho lze 6 až 20V DC. Navíc

nepotřebujeme breadboard, abychom do něj

něco zapojili, drátky můžeme rovnou strkat do

jeho zdířek.

7 Wikimedia Foundation, Inc. Serial port – Wikipedia. Wikipedia: The Free Encyclopedia. [online]. 26
October | 2005, | 1 | December | 2022 | [31.1.2023] | Veřejně | dostupné | z
https://en.wikipedia.org/wiki/Serial_port

4 Konektor DE-9 přes který původně probíhala komunikace COM (volné dílo)

5 Arduino Leonardo

Jeho hlavní výhodou je ale schopnost posílat do počítače klávesnicové vstupy a to

bez použití jiných kabelů, než micro USB, kterým ho napájíme. Můžeme pomocí něj

tedy ulehčit uživatelovi práci a například za něj napsat heslo, nebo pomocí

klávesové zkratky Win + L zamknout jeho počítač, pokud detekuje jeho

nepřítomnost.

Breadboardy


Breadboard je destička, pomocí které se dají

navrhovat a testovat obvody bez pájení. Sloty

v breadboardu jsou spojené do řádků, kraje

velkých breadboardů pak do sloupců. Dovolují

vývojářům a kutilům zastrčit do nich součástky,

vyzkoušet funkcionalitu, a pak součástky zase

vyndat a použít znova. Breadboardy mívají na

stranách zářezy anebo výstupky, aby se daly


spojit pro jednodušší práci.

Jednopinové spoje

Drátky kompatibilní s breadboardy a jinými

součástkami. | Dají | se | pořídit | v jakékoliv

kombinaci konektorových pohlaví.

LCD displej

LCD displej, který používám má rozlišení

128x32 pixelů. Umí zobrazovat jen jednu

barvu, a to světle modrou. Komunikuje

s Arduinem pomocí protokolu IIC. Lze na něm

zobrazovat jednotlivé pixely, čáry, obrazce,

anebo rovnou obrázky, či text s vlastním

fontem. Víc o zobrazování obrázků anebo


používání vlastních fontů najdete v sekci použitý software.

6 Příklad použití breadboardů

7 Přiklad použití jednopinových spojů

8 Příklad použití displeje k zobrazení mého pseudonymu při startu obrazovkového modulu

Reproduktor


Reproduktor, který používám má výkon

2W a impedancí 8Ω. Výborně reprodukují

vysoké frekvence, u těch nižších jsou tišší

a reprodukovaný zvuk je méně kvalitní.

Kvalita přehrávaného audia je ale také

limitována | přehrávacími | schopnostmi

Arduina, které dokáže z SD karty přehrát

audio maximálně o 8 bitové hloubce a

vzorkovací frekvenci 16KHz.


Červené tlačítko s krytkou

Je vůbec potřeba důvod mít červené

tlačítko s krytkou? To je snad sen

každého kutila, někam takové tlačítko

zakomponovat! Tlačítko se bez matice

vloží do krytky a matice se pak nandá na

závit tlačítka. Krytka pak pevně drží a

chrání před nechtěným odpálením.

Páčkový přepínač

Běžný přepínač, který vypadá, jako z kokpitu letadla.

Jeden dokáže přepínat dva oddělené obvody zároveň.

Přichycovací mechanismus se silně podobá uchycovacímu

mechanismu u červeného tlačítka.

Čtečka micro SD karet a karta samotná

Jeden z mála modulů, který je napájen 3.3V místo 5. Co se

týče kapacity micro SD karty, úplně by stačilo 64MB.

Arduino dokáže přehrát jen velmi jednoduché soubory,

které nemají šanci zabrat moc místa, a to i při uložení ve

formátu bez komprese, jako je .wav.

9 K reproduktoru bylo potřeba připájet konektory

10 "Pane prezidente, rozhodnutí je na Vás."

11 Běžná páčka, běžný přepínač.

12 I dnes může několik desítek MB bohatě stačit


PNP tranzistor

PNP tranzistory jsou něco jako velmi

jednoduchý programovací if. Propouští

proud z emitteru do kolektoru jenom když je

napětí v bázi zhruba o půl voltu nižší než v

emitteru. Tranzistory fungují jen při nízkých

napětích a nízkých proudech. Při vyšších

zatíženích se používají relé.

680KΩ rezistor

Bez pulldown odporu na lince signálu

z obrazovkového do zvukového modulu se

stávalo, že zvukový modul začal sám o sobě

hrát. U jiných modulů se tohle zatím nestalo.

Drát do počítače a zpět

Je docela jedno, co za drát použijete, ale

musí být dost dlouhý. Drát, který jsem použil

já, byl červený CYA 1, nejlevnější druh

prodávaný po metrech, vhodný víceméně na

všechny nízkonapěťové účely.

Spínač na zámek

Stejně jako většina visacích zámků lze i tento

být jednoduše obejit, ale šlo mi spíš o

estetickou hodnotu. Je to další vychytávka,

která zaujme kutily.

LED diody

Jak jinak indikovat zapnutí, provoz, nebo funkcionalitu? Žárovky by potřebovaly víc proudu než by Arduino bylo

schopno poskytnout a doutnavka běží na AC.

13 Kupička silikonu na nožičkách

15 Jeden chybí, ten už byl použit

14 Zhruba 25m kabelu. Sestříhat a použít.

16 Záložní klíček se vždycky hodí

17 Osvětlení jako v nightclubu

RFID-RC522 a MIFARE čip

Pomocí | tohoto | modulu | lze | zapisovat | i | číst
z kompatibilních | čipů a | čipových | karet | MIFARE

CLASSIC.

Dvojitý terminál

Takovýto šroubovací terminál je nejjednodušší a

nejspolehlivější způsob, jak připojit něco k Arduinu kabelem. Šroubek se vyšroubuje a do slotu se nacpe

obnažený kabel nebo drát. Šroubek se zase zašroubuje

a kabel se přiskřípne mezi konektory. I přes mírná

škubání a popotahování je pak kabel dobře připojen.

Malé šroubky

Těmito šroubky jsem přišrouboval k sobě části 3D tištěné

krabičky na finální produkt. Krásně se také vejdou do

zdířek v Arduinu Leonardo, takže se dá nádherně

připevnit ke stropu krabičky.

18 RFID modul i s čipem a čipovou kartou


19 Jeden slot volný, v druhém slotu pevně připojený kabel

20 Netuším, co je to za kov. Možná mosaz?

## Použitý software

Word

Myslím si, že nikoho nepřekvapí, že k psaní této práce byl použit Microsoft Word,

konkrétně Word 2019.

Arduino IDE


Integrované vývojové prostředí, neboli IDE je

program určení k psaní dalších programů. IDE

většinou podporují jen některé programovací

jazyky, nebo jen některé platformy. K vývoji

programů na Arduino potřebujeme takové IDE,

které by nám dovolilo nejen napsat program

v C++, ale i ho bezbolestně nahrát do Arduina.

Jedno takové vyvinuli sami tvůrci Arduina.

Nenabízí sice našeptávání, či jiné pokročilé

funkce, ale jednoduše se přes něj nahrávají

programy na Arduina. Stáhnout se dá na

https://www.arduino.cc/en/software.

Když si IDE nainstalujeme, musíme ještě

připojit samotné Arduino k počítači. Každý

model má nějaký USB port, přes který ho lze

jednoduše připojit. Starší modely mívají mini

USB, novější mají micro USB a ty nejnovější

podporují USB C.

Spusťme Arduino IDE. Objeví se nám

šablona nového projektu s dvěma metodami, setup() a loop(). Jak napovídají

komentáře, kód v metodě setup() se spustí jednou při startu Arduina a metoda loop()

se bude volat donekonečna.

22 Připojené Arduino Nano

21 Prázdný projekt v Arduino IDE

Arduino se programuje v C++. Můžeme se tedy rovnou pustit do programování.

Chceme-li například, aby Arduino po zapnutí rozsvítilo LED diodu, kterou má v sobě

zakomponovanou, vložíme do metody setup() následující kód:

pinMode(LED_BUILTIN, OUTPUT);

digitalWrite(LED_BUILTIN, HIGH);

Tím Arduinu řekneme, že pin LED_BUILTIN

bude výstupní a že do něj chceme zapsat

hodnotu HIGH, čili pustit do něj proud.

Chceme-li do Arduina kód zapsat, musíme

nejdříve IDE říct, co máme za Arduino a přes

který COM port s ním má komunikovat. To

nastavíme v dropdown menu Tools na horní

liště okna. Jakmile si navolíte správné

nastavení, můžete kliknout na ikonku šipky


vlevo nahoře. Tím dáte IDE povel zkompilovat a poslat program do Arduina.

Pokud jste zvolili správná nastavení, mělo by se Arduino rozblikat a pak by mělo

rozsvítit dvě ze svých diod. Jedna indikuje zapnutí a tu druhou jste zapnuli

programem.

Pokud | se | vám | v konzolovém
výstupu | IDE | objevila | chybová
hláška, | není | třeba | panikařit.

Pravděpodobně jste špatně nastavili

něco v Tools. Vraťte se tam a zkuste

jiná nastavení.

Kdybyste chtěli, aby dioda po

zmáčknutí tlačítka zhasla, můžete

do setup() přidat ještě:

pinMode(3, INPUT_PULLUP);

23 Rozbalené menu Tools


24 Výsledek úspěšného a neúspěšného pokusu o nahrání programu

Čímž řeknete Arduinu, že pin D3 bude vstupní a dokud ho nespojíte s jedním

z uzemňovacích GND pinů, tak z něj Arduino vyčte hodnotu HIGH. Do loop() pak

přidejte ještě

if (digitalRead(3) == LOW){

digitalWrite(LED_BUILTIN, LOW);

}

Potom jeden pin tlačítka spojte s D3 a druhý s GND. Dokud nezmáčknete tlačítko,

dioda bude svítit, ale jakmile ho zmáčknete, dioda zhasne.


Nemusíme ale všechno programovat sami.

Arduino | IDE | také | obsahuje | ukázky.

V dropdown menu File v horní liště okna je

můžeme najít pod volbou Examples. Ukázky

mohou pocházet jak od tvůrců Arduina, tak od

developerů různých knihoven.

Podívejme se třeba, jak se podle tvůrců

Arduina dělá, aby LED dioda postupně

zhasínala a zase se rozsvěcela. Najděte

v Examples položku 01.Basics, a v ní najděte

Fade. Po rozkliknutí se vám načte už hotový

projekt.

Tyto projekty jsou většinou velmi dobře

okomentované, aby se z nich dalo jednoduše

vyčíst, která část co dělá.


27 Tudy se k ukázce Fade dostaneme

26 Tlačítko nezmáčknuto, dioda svítí | 25 Tlačítko zmáčknuto, dioda přestala svítit


Podívejme se tedy na kód. Můžeme z něj vyčíst, že program bude do pinu 9 velmi

rychle střídavě posílat a neposílat proud v poměru, který se každých 30ms zvýší o

5
255

, dokud nebude na 255
255

. Jakmile této hodnoty dosáhne, bude zase poměr

postupně snižovat dokud nedosáhne nuly. Když k pinu 9 připojíme LED diodu,

uvidíme ji postupně zhasínat a zase se rozsvěcet. Tím jsme měli možnost zjistit

nejen jak funguje PWM, ale i jak ho v projektu použít.

28 Ukázka Fade v Arduino IDE

PyCharm Professional

PyCharm je IDE vytvořené speciálně

pro práci s Pythonem. Vyvinula jej

česká společnost JetBrains, která je

mimochodem také zodpovědná za

vytvoření | programovacího | jazyka

Kotlin, což je nadstavba na Javu.


PyCharm jako takový má dvě varianty, Community Edition, která je zdarma a open-

source, a Professional Edition, která je placená a proprietární. Liší se hlavně

v pokročilých funkcích jako podpora databází a SQL, která chybí v bezplatné edici.

Jako student ale mám k dispozici edici Professional zdarma.

GIMP

Program k manipulaci s obrázky pod licencí

GNU je freewarová imitace Photoshopu.

Využil jsem jej hlavně k tvorbě pixel artu,

který jsem pak zobrazoval na displeji

obrazovkového modulu.

Abych redukoval množství informací, které se musí na Arduino vejít, vytvořil jsem

vždy nejprve návrh jak bude nějaká scéna či animace vypadat a poté jsem ji rozdělil

na jednotlivé komponenty a ty teprve nahrál na Arduino.

image2cpp

I2CPP je jednoduchá webová aplikace,

která je schopná konvertovat obrázek na

bytecode, se kterým je Arduino schopno

pracovat. Umí ale fungovat i obráceně,

tzn. z bytecodu udělat obrázek.

Bez tohoto programu bych musel buď všechny obrázky přepisovat na bytecode

ručně, anebo se obejít bez nich.

29 Práce v prostředí PyCharm

30 Práce s GIMPem

31 Konverze malé bitmapy na kód.


Audacity

Audacity | je | freewarový

prográmek, pomocí kterého jsem

překodekovával zvukové soubory

pro audio modul. Arduino totiž

nemá dost rychlé CPU, aby

zvládlo v reálném čase přečíst a

dekomprimovat | příliš | náročný

audio soubor.

Bohužel se při zjednodušování audia pro Arduino výrazně zhorší kvalita zvuku.

Snímkovací frekvence se musí snížit na 16 000 za sekundu a ukládat se mohou jen

hodnoty od 0 do 255, takže nelze reproduktor ovládat tak jemně, jak by bylo potřeba.

Na druhou stranu reproduktor, který používám, není moc závratné kvality, takže i

s vysokou kvalitou zdroje zvuku by to neznělo o moc lépe.

GitHub

GitHub je společnost, u které si můžete

vytvořit libovolný počet programovacích

projektů, tzv. repozitářů, a poté do nich

v balících posílat změny v kódu. Všechny

iterace kódu jsou uloženy a lze se

jednoduše vrátit k jakékoliv verzi.

FontConvert

FontConvert je jednoduchý konzolový

prográmek, který ze souboru s fonty přečte,

jak jednotlivé znaky vypadají, a pak je

konvertuje na bitmapy, které uloží ve

formátu | kompatibilním | s grafickými

knihovnami na Arduino.

32 STARTU46.WAV otevřený v Audacity

33 Chesters-CZ/Enhanced-power-button je repozitář tohoto projektu


34 Trochu návrat do éry MSDOSu

Tinkercad

Další webová aplikace, ale tentokrát na

design 3D tištěného šasí na všechny 3

moduly. Dovoluje pracovat v reálných

rozměrech a následně exportovat do

formátů, které podporuje většina slicerů.

Draw.io

Draw.io je bezplatná webová aplikace,

která se dá stáhnout i jako lokální.

Výborně se v ní dělají profesionálně

vypadající schémata a flowcharty.

35 Tinkercad dovoluje nejen modelovat, ale i komentovat.

36 Rozpracované schéma obrazovkového modulu

## Použité knihovny

Tento projekt by nebylo možné reálně začít, kdyby nebylo vývojářských hrdinů, kteří

naprogramovali knihovny, které jsem použil. Využil jsem i některé zabudované

knihovny, které zde nejmenuji.

V pythonovém scriptu jsem nepoužil žádné externí knihovny.

Adafruit GFX a SSD1306

Tyto knihovny se starají o vykreslování grafiky a následnou komunikaci s displejem.

Vyvinula je společnost Adafruit Industries, LLC, která designuje, vyrábí a prodává

různé součástky k použití s Arduiny, Raspberry Pi a dalšími mikrokontrolery.

TMRpcm

Knihovna, která si z připojené SD karty přečte audio soubor a pokusí se ho přehrát.

Jméno jejího autora je neznámé, schovává se pod pseudonymem TMRh20.

SpaniakosAES

Implementace šifrovacího standardu AES. Podporuje všechny tři verze, AES-128,

AES-192 i AES-256. Jejím autorem je řecký programátor Georgios Spanos.

Implementace base64

Base64 je způsob, jak konvertovat binární kód do textu pomocí písmen, čísel a pár

znamínek. Jejím autorem je Densaugeo.

CzechKeyboard

Upravená verze knihovny Keyboard od Arduina s upravenou konfigurací pro české

keyboard layouty. Vytvořil ji Michal Altair Valášek.

Easy MFRC522

Knihovna pro jednoduché použití RFID čtečky RC522. Vytvořil ji Pablo Sampaio.

## Popis jednotlivých modulů

V této sekci najdete detailní popis fungování všech tří modulů i pythonového scriptu.

Obrazovkový modul


Tento modul se stará o

zapínání | počítače | a
zobrazování | informací | na
displeji. | Komunikuje | také

s pythonovým scriptem na

počítači, aby získal aktuální

datum a čas.

Tento modul zahrnuje:

- Arduino Nano
- Displej
- 2 tranzistory
- Velké červené tlačítko

Popis fungování

setup()

Arduino začne tím, že si inicializuje potřebné hodnoty a pak zobrazí hezkou animaci.

Poté se pokusí přes sériovou komunikaci do počítače poslat zprávu a čeká, jestli

mu přijde odpověď.

Pokud ne, znamená to, že spojení s pythonovým scriptem nebylo navázáno.

Arduino o tom informuje uživatele a pokračuje metodou loop().

Pokud odpověď dostane, informuje o tom uživatele a z odpovědi si přečte jaký

„spořič obrazovky“ bude používat. Tento spořič obrazovky ale doopravdy nic

nešetří, jde spíš jen o využití displeje při nečinnosti. Jsou tři možnosti: odrážející se

animace, která připomíná spořič obrazovky starých DVD přehrávačů, zobrazování

času anebo zobrazování data.

37 Schéma obrazovkového modulu

Pokud si uživatel zvolil odrážející se animaci, Arduino nepotřebuje žádné další

informace. Potvrdí přijetí zprávy a pokračuje metodou loop().

Pokud si uživatel zvolil datum nebo čas, Arduino potvrzením přijetí zprávy také

zažádá počítač o informace o čase. Ty mu pythonový script pošle jako počet

milisekund od půlnoci toho dne. Arduino si informaci uloží a pošle potvrzení přijetí.

Bude-li Arduino zobrazovat datum, dostane ještě informaci o datu ve formátu ISO,

tzn. YYYY-MM-DD. Arduino si data zpracuje a potvrdí přijetí.

loop()

Arduino si nejdříve vyčistí display buffer, aby mu na displeji nezbývaly zbytky

z předchozích zobrazování.

Poté zkontroluje, jestli uživatel právě mačká tlačítko.

Uživatel nemačká tlačítko

Arduino zkontroluje, zda od RFID modulu nepřichází nějaký signál. Pokud ano,

zobrazí příslušnou hlášku spolu s ikonou. Potom pokračuje dále.

Pokud je tlačítko nezmáčknuté alespoň 100 čtecích pokusů za sebou, začne

zobrazovat spořič obrazovky. Pokud to ještě nebylo 100 pokusů, zobrazí Arduino

na displeji piktogram spícího Arduina, čímž uživatele informuje o blížícím se

spuštění spořiče.

Uživatel mačká tlačítko

Arduino zkontroluje, je-li spínač na klíček odemknut. Pokud ne, zobrazí na displeji

informační hlášku. Pokud ano, informuje pythonový script o statusu tlačítka, začne

do počítače posílat vypínací/zapínací signál a na obrazovce ukáže piktogram prstu

mačkajícího tlačítko, aby informoval uživatele o zpracování jeho akce.

Jakmile uživatel přestane tlačítko mačkat, Arduino přestane posílat do počítače

signály a zkontroluje, jestli je audio modul připraven přehrát nějakou skladbu. To

zjistí tak, že do něj audio modul posílá signál.

Audio modul je připraven

Arduino začne do audio modulu posílat signál a čeká, až to audio modul zjistí a

přestane posílat signál zpátky. Do té doby zobrazuje na displeji načítací animaci.

Pokud audio modul neodpoví zhruba do tří sekund, Arduino o tom informuje

uživatele přes chybovou hlášku na displeji a spustí loop() znovu.

Pokud audio modul odpoví, loop() se spustí bez chybové hlášky.

Audio modul není připraven

Pokud audio modul právě signál neposílá, znamená to buď že už nějakou znělku

nahrává z SD karty, anebo že není zapnutý. Každopádně by povel ke spuštění

písničky nezpracoval, takže Arduino žádný nepošle, ale jen oznámí uživateli proč

nic nehraje.


Audio modul

Audio | modul | na | povel

obrazovkového modulu načte

náhodnou skladbu z SD karty

a přehraje ji.

Tento modul zahrnuje:

- Arduino Nano
- Čtečku micro SD karet
- Reproduktor
- 2 tranzistory
- Rezistor

Popis fungování

setup()

Po zapnutí si Arduino ověří, že je připojená SD karta a jestli je na ní aspoň jeden

audio soubor k přehrání. Pokud ano, inicializuje stavy pinů a nastaví hlasitost

38 Schéma audio modulu přehrávaného zvuku na 5, což je nejvyšší hlasitost bez zkreslení. Pokud ne, oznámí

kde se stala chyba pomocí Morseovy abecedy a dále již nepokračuje.

Nebyl-li detekován problém, Arduino si načte náhodný seed, který bude používat

pro generování náhodných čísel. Nakonec už jen započne komunikaci s SD kartou

a přehraje z ní soubor BOOT.WAV, čímž uživatele upozorní, že je připraven.

loop()

Na začátku loopu Arduino začne posílat do obrazovkového modulu signál.

Obrazovkový modul tím ví, že je audio modul připraven zpracovat povel. Arduino

potom zkontroluje, jestli od obrazovkového modulu povel už nepřišel. Pokud ne,

spustí loop() znovu.

Pokud povel přišel, Arduino potvrdí obrazovkovému modulu přijetí tím, že do něj

přestane posílat signál a přijetí povelu také oznámí počítači přes sériovou

komunikaci. Následně pokud nějaký zvuk už hraje, zastaví jeho přehrávání a hodí

si n-strannou kostkou, kde n je přednastavený počet skladeb na SD kartě. Toto číslo

pak vycpe nulou, je-li třeba, a dosadí ho do STARTU__.WAV. Tento soubor pak

přehraje a jeho přehrání také oznámí počítači. Nutno poznamenat, že Arduino neví,

jestli je reproduktor odpojen či připojen a signál do něj pouští vždy.

S dalším spuštěním metody loop() pak počká čtvrt sekundy po tom, co přestane od

obrazovkového modulu dostávat signál.

RFID moduly

Pro tento projekt je nutné buď využívat dva RFID moduly zároveň, nebo si pro

nahrání dat na čipy dočasně přeprogramovat Arduino. Funkcionalita obou variant je

rovnocenná, ale může být jednodušší mít

k dispozici dedikovaný nahrávací modul.

Zapisovací (šifrovací) modul

Tento modul | zašifruje | uložené heslo

šifrovacím klíčem za použití inicializačního

vektoru, zakóduje ho do base64, a zapíše

39 Schéma šifrovacího modulu na libovolný počet čipů spolu s informací, jestli po odebrání čipu zamknout počítač

či ne.

Před nahráním programu na Arduino je nutné, aby uživatel upravil výchozí hodnoty v projektu na své. Šifrovaný text (heslo) může obsahovat alfanumerické znaky a

symboly a musí mít délku menší než 48 znaků. Inicializační vektor může být libovolné celé číslo od 0 do zhruba 18.4 trilionů⁸⁹ Šifrovací klíč se zadává jako text

a může také obsahovat alfanumerické znaky a symboly. Jeho délka ale musí být

přesně 16, 24 nebo 32 znaků. Délka šifrovacího klíče také určuje bezpečnost šifry,

buďto AES128, AES192, nebo AES256.

Tento modul zahrnuje:

- Arduino Nano
- RFID modul RC522
- 2x tlačítko
- Červená LED dioda
- Zelená LED dioda

Popis fungování

setup()

Po zapnutí Arduino pouze naváže kontakt s počítačem, komunikuje-li, a inicializuje

čtečku čipů.

loop()

Arduino inicializuje vstupní a výstupní piny a rozsvítí obě diody. Přes sériovou

komunikaci pošle instrukce na používání; pokud chce uživatel, aby se jeho počítač

po ztrátě spojení s čipem zamkl, má zmáčknout tlačítko u zelené diody, pokud ne,

zmáčkne tlačítko u té červené.

8 Jde o 64 bitový kladný integer. Jeho maximální hodnota je 2⁶⁴, což je 18 446 744 073 709 551 615. 9 UtkarshPandey6. Maximum value of unsigned long long int in C++. In: Sandeep Jain. GeeksforGeeks. [internet]. A-143, 9th Floor, Sovereign Corporate Tower,
Sector-136, Noida, Uttar Pradesh – 201305: GeeksforGeeks, 03 Dec, 2020 [11.2.2023]. Veřejně dostupné na https://www.geeksforgeeks.org/maximum-value-of-unsigned-long-long-int-in-c/

Když uživatel zvolí, Arduino zhasne diodu u nezvolené volby a zkontroluje délku

šifrovacího klíče. Nabývá-li délka jedné ze správných hodnot, zašifruje heslo a

výsledek zakóduje do base64, aby se dalo zapsat na čip. Pak si připraví ještě délku

hesla zakódovaného v base64 a zdali se má počítač vypnout po ztrátě kontaktu

s čipem, | a jakmile uživatel
přiloží | kompatibilní | čip | ke

čtečce, tyto informace na něj

zapíše a znovu spustí loop().

Čtecí (dešifrovací) modul

Tento modul přečte zašifrované

heslo z RFID čipu, pomocí

přednastaveného šifrovacího


klíče jej dešifruje a pošle do počítače jako klávesnicový vstup. Poté podle nastavení,

které si také přečte z čipu, po odebrání čipu z dosahu čtečky buď zamkne počítač,

nebo neudělá nic.

Jako u šifrovacího modulu je i tady nutné upravit program před nahráním na čip.

Uživatel si ale tentokrát nemůže zvolit nový šifrovací klíč ani inicializační vektor,

musí použít ty, které použil při šifrování, jinak Arduino nedešifruje heslo správně.

Heslo samotné ale není třeba do tohoto modulu ukládat, Arduino ho zjistí z čipu.

Tento modul zahrnuje:

- Arduino Leonardo
- RFID modul RC522

Popis fungování

setup()

Po zapnutí se Arduino pokusí navázat sériovou komunikaci s počítačem a

inicializuje RFID modul a klávesnicovou komunikaci.

40 Schéma dešifrovacího modulu

loop()

Arduino zkontroluje délku šifrovacího klíče a podle ní se připraví na příslušnou

úroveň šifry k dešifrování. Pak každých 50ms zkontroluje, jestli je v dosahu čtečky

RFID čip. Jakmile je, počká ještě další desetinu sekundy, aby se mohl čip více

přiblížit, a spojení bylo stabilnější. Poté si přečte všechny potřebné informace a

dešifruje heslo, které pak pošle do počítače jako klávesnicový vstup.

Pokud bylo na čipu zapsáno, že se počítač má zamknout jakmile se čip odebere od

čtečky, Arduino bude každých 100ms ukončovat a opět navazovat kontakt s čipem

a bude ověřovat, že má pořád stejné ID.

Aby nedošlo ke zbytečnému vyrušení uživatele kvůli pár špatným pokusů o přečtení,

povel zamknout se se počítači pošle až s desátým neúspěšným pokusem.

Povel samotný se pošle jako klávesová zkratka Win + L, která, alespoň na

počítačích se systémem Windows 2000 a novějším,

10 „zamkne“ počítač, tzn.

odhlásí právě přihlášeného uživatele aniž by ukončila běžící programy.


10 Wikimedia Foundation, Inc. Windows key – Wikipedia. Wikipedia: The Free Encyclopedia. [online].
25 | April | 2006, | 5 | January | 2023 | [11.2.2023] | Veřejně | dostupné | z
https://en.wikipedia.org/wiki/Windows_key

41 Schéma propojených modulů

## Šasí

Tento projekt by byl relativně úplný i bez obalu, jen jako několik součástek

propojených drátky. Na druhou stranu, průměrný člověk pracující v sedavém

zaměstnání by si pravděpodobně na stůl nedal něco, z čeho koukají obnažené

kontakty.

Navrhl jsem tedy jednoduchý 3D model krabičky, do které jsem postupně přidával

díry na různé periferie a kabeláž. Byl to můj vůbec první pokus o práci s 3D

tiskárnou, a tak se mnohé nepovedlo. Některé sloty byly moc blízko u sebe, jiné

moc daleko a pár jich dokonce bylo moc malých.

Všechny mouchy se mi podařilo vychytat bez nutnosti cokoli tisknout znovu. Díry,

co chyběly jsem provrtal, ty, které byly moc malé jsem zvětšil a ty, které byly na

špatném místě jsem buď nahradil, anebo jsem se obešel bez nich.

Možná jsem se mohl pokusit model vylepšit, aby byl perfektní bez jakýchkoli

modifikací hrubou silou, ale vzhledem k tomu, že 3D tisk mi zajišťoval vedoucí práce


z jeho dobré vůle pomocí jeho osobní 3D tiskárny a jeho filamentu, nechtěl jsem

zbytečně zneužívat jeho pohostinnost.

Základ krabičky

Základem krabičky je kvádr bez horní

a přední strany. Aby se mi projekt lépe

sestavoval do krabičky, rozhodl jsem

se ponechat Arduina v breadboardech

a ty pouze přilepit k podlaze krabičky.

Abych ušetřil trochu místa, Arduino

z RFID modulu jsem připevnil na strop

krabičky. Proto je také jedna z dírek

tak vysoko. Tyto dírky bylo potřeba zvětšit, protože jsem při jejich návrhu nepočítal

s tloušťkou celého kabelu, nýbrž jen konektorové části portu.

42 Šikmý pohled na základ krabičky zepředu

Tyto dírky jsou potřeba, aby bylo možné

Arduina zapojit do počítače. Celkem je

potřeba mít v počítači 3 volné USB-A

porty, anebo si pořídit USB hub. Ta čtvrtá

osamocená dírka na pravé straně je na

drátky z počítače.

Vedle této dírky si také můžete všimnout

ztenčené stěny. Tam jsem se snažil o

lepší propustnost elektromagnetických

vln. Když se totiž podíváme na tuto stranu

zvenčí, | najdeme | tam | prostor | na

ponechání čipové karty.

V rozích jsou také umístěny malé otvory

44 Pohled shora na stropní panel; 45 Pohled na stropní panel zespodu; 46 Boční panel

na šroubky. Tyto otvory se tiskárně ale

pravděpodobně | nepodaří | vytisknout

přesněji než malý ďůlek. To ale stačí na to,

aby se tam dala opřít špička šroubku.

Zbytek se tam dá našroubovat hrubou silou.

Stropní panel

Hlavní vlastností tohoto panelu je několikero

kulatých otvorů na reproduktor, tlačítko,

spínač na klíček, displej, spínače a LED

kontrolky. Zespoda jsou na panelu výstrupky

na připevnění Arduina Leonardo z RFID

modulu. Panel sám o sobě totiž není dost

tlustý na to, aby šroubek neprošel skrz.

Boční panel

Tento panel už jen zavírá krabičku a nemá

na sobě žádné speciální výstupky.

43 Pohled zblízka na prostor pro čipovou kartu

## Závěr

Tento projekt byl jako vztah. Když jsem na něm začal pracovat, bylo to něco, co

jsem dělal jen tak pro radost. Sem tam jsem na něm zapracoval, ale žádné velké

pokroky jsem neudělal, dokud jsem se nedozvěděl, že to s ním mohu někam

dotáhnout. Jakmile mi byl uznán jako maturitní, začal jsem na něm pracovat

dennodenně. Trávil jsem na něm čas a utrácel jsem kvůli němu peníze. Byly i týdny,

kdy jsem na něm vůbec nepracoval, ale nakonec se mi povedlo to dotáhnout do

šťastného konce.

Cítím, že jsem odvedl perfektní práci na něčem, co mě opravdu bavilo. Nedovedu

si představit jak bych vůbec mohl tento projekt nějak zlepšit. Ani teď, ani v průběhu

práce na něm.

Odnáším si z něj mnohé. Naučil jsem se programovat v C++, vytvářet modely k 3D

tisku, porozumět jednoduché elektronice a jejím principům, naučil jsem se pájet a

sestavovat obvody a ještě jsem mnoho dalších dovedností oprášil. Jsem toho

názoru, že jsem tím dokázal nejen, že umím použít znalosti, které jsem se naučil ve

škole, ale i že jsem schopen si informace dohledávat a co je potřeba i sám sebe

naučit.

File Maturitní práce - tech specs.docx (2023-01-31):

MATURITNÍ PRÁCE

Obohacené zapínací tlačítko se zabezpečovací funkcionalitou

Studijní obor: IT

Třída: C4

Školní rok: 2022/2023

Jméno a příjmení: Vít Bezouška

Vedoucí práce: Radek Lampíř

Abstrakt

Abstract

Klíčová slova

Prohlašuji, že jsem tuto práci vypracoval(a) samostatně a použil(a) jsem literární prameny a informace, které cituji a uvádím v seznamu použité literatury a zdrojů informací.

V Praze dne …………. ……..……………………

jméno a příjmení

Obsah

Úvod 7

Nápad a první krůčky 8

První použití Arduina 8

Nedostatek RAM 9

Komunikace mezi kalkulačkami Texas Instruments 10

Komunikace mezi Arduiny 11

Shrnutí 11

Cíle práce 13

Zabezpečovací zařízení 13

Zamezit zapnutí počítače 13

Zamezit přístupu k datům anebo k uživatelskému účtu 13

Ukazatel času nebo dnešního data 14

Prezentovatelné šasí 15

Průběh práce 16

Začátek zabezpečování 16

Problémy s upraveným firmwarem Una 17

Haló, tady Windowsovi! 17

Pčtrosí řešení na přestupný problém 18

Failsafe design komunikace 19

Ostatní vlastnosti skriptu 19

Relativně Frantické Inkódovací Dilema 20

AES aneb 16 bytů k absolutní bezpečnosti 20

Princip šifrování 20

Zranitelnost vůči bruteforce útokům 21

Zranitelnost vůči přečtení programového kódu 22

Zranitelnost vůči připojení do cizího počítače 23

Jak zapsat zašifrované heslo na čip? 23

Implementace 24

Murphyho zákon 24

Lokaliya4n9 probl0mz 25

Châssis de acide polylactique 25

Jak Vítek na krabičce dělal 26

Design 26

Struktura práce 28

Titulní strana 28

Abstrakt, Abstract, Klíčová slova 28

Prohlášení 28

Obsah 29

Úvod 29

Vlastní text práce 29

Závěr 30

Seznam použitých zdrojů 30

Seznam příloh a přílohy 31

Základní formátování 31

PowerPointová prezentace (či google prezentace) 32

Obhajoba maturitní práce a názorné ukázky praktické části maturitní práce 32

Způsob odevzdání maturitní práce 33

# Úvod

Tato práce popisuje mnou navržené a vytvořené zabezpečovací zařízení pro stolní počítač a jeho vlastnosti.

Funkcionalita je rozdělená mezi tři mikrokontrolery Arduino, konkrétně dva modely Nano a jeden model Leonardo. Jedno Nano ovládá displej, zapíná počítač a komunikuje s pythonovým scriptem. Toto Nano a k němu připojené periferie budu nazývat displejovým nebo obrazovkovým modulem. Druhé z Nan na povel displejového modulu přečte z micro SD karty audio soubor a přehraje ho. Nazývejme jej zvukovým modulem. Úkolem Arduina Leonardo je přečíst zašifrované heslo z přiloženého RFID čipu nebo karty, dešifrovat ho, a následně ho poslat jako klávesnicový vstup do počítače. To je modul čipový.

Zabezpečení samotné je zajišťováno třemi funkcemi. Zařízení zaprvé omezuje přístup k napájecímu tlačítku počítače nepovolaným osobám tak, aby nemohly počítač vypnout ani zapnout. Zadruhé pracuje jako password manager hesel uložených na RFID čipu či kartě. Poslední funkcí je možnost nastavení automatického odhlášení z uživatelského profilu v systému Windows po odejmutí čipu či karty ze čtecího senzoru.

Součástí práce bylo navrhování a sestavování hardwarových obvodů, navrhování 3D tištěného šasí, programování mikrokontrollerů Arduino v C++ a vytváření pythonového scriptu, který zprostředkovává komunikaci mezi počítačem a jedním z Arduin.

# Použité materiály

Na každý projekt je potřeba trocha hardwaru. Zde je seznam toho, co bylo použito na tento projekt.

Počet | Součástka
2 | Arduino Nano
1 | Arduino Leonardo
1 | Breadboard malý
2 | Breadboard velký
>50 | Jednopinový spoj
1 | IIC LCD displej 128x32px, jednobarevný
1 | Reproduktor 2W 8Ω
1 | Velké červené tlačítko
1 | Odklápěcí kryt na velké červené tlačítko
3 | Páčkový přepínač
1 | Micro SD modul
1 | Micro SD karta >8MB
4 | PNP tranzistor
1 | Malý 10KΩ rezistor
2 | Kabel, který dosáhne od krabičky k PW pinům
1 | Spínač na zámek (s klíčkem)
4 | Libovolná LED dioda
1 | RFID modul RC-522
1 | MIFARE Classic čip
1 | Šroubovací terminál na dva drátky
12 | Šroubků 2x10mm

# Popis jednotlivých součástek


Důležité je vědět nejen co použít, ale i jak to použít.

## Arduino Nano

Nejstarší Arduino, které se dnes běžně používá. Po připojení k počítači kabelem se ohlásí jako zařízení připojené přes emulovaný COM port.

### Co je COM port?

1 Arduino Nano


COM porty byly sériové porty, které se dříve používaly k připojení tiskáren, obrazovek a dalších periferií v dobách před USB.

Dnes už na počítačích tyto porty fyzicky nenajdeme, ale některé periferie si i tak vyžádají, aby jim byl přidělen virtuální COM port, protože jinak komunikovat neumí. Operační systém tedy „vytvoří“ nový COM port, který těmto zařízením přiřadí. Ten nový port sice fyzicky neexistuje, ale programy, ani připojená zařízení rozdíl nepoznají.

2 Konektor DE-9 přes který původně probíhala komunikace COM (volné dílo)

Proč se ale tato stará technologie pořád používá? Hlavním důvodem je, že implementace komunikace přes COM je relativně nenáročná a může probíhat i se zařízeními připojenými přes běžné USB.

Nevýhodou tohoto způsobu komunikace je velmi nízká propustnost dat, ta se pohybuje v jednotkách až desítkách kilobitů za sekundu,[^1] ale zařízení, která COM využívají, nepotřebují, aby komunikace byla rychlá. Naprosto jim stačí, že nějaká vůbec je, protože by vyšší rychlosti buď nestíhala, anebo neposílají tak velké objemy dat, aby vyšší propustnost měla nějaký znatelný dopad.

# Účel zařízení

Hlavním cílem tohoto modulu je pomoct i laickému uživateli zabezpečit jeho počítač před těmi nejobecnějšími kyberhrozbami a navíc trochu zpříjemnit jeho používání.

## Ochrana zapnutí počítače


Spínač na klíč funguje jako prevence neoprávněného zapnutí. Tento způsob ochrany je sice velmi jednoduchý, ale nelze ho obejít, aniž by byly zanechány známky vniknutí. Stačí na šroubky na krabičce a od počítače nalepit bezpečnostní nálepky. Když se uživatel vrátí k počítači a uvidí, že se do něj někdo pokoušel dostat, může si okamžitě změnit hesla a zabránit tak neoprávněnému přístupu do svých účtů.

3 Příklad použití bezpečnostní nálepky k zabezpečení krabičky čokoládových bonbónů

## Ochrana před fyzickými keyloggery

Keylogger je zařízení, které si zapamatovává uživatelské vstupy aniž by je blokovalo a je schopno je poté poskytnout útočníkovi, který z nich může vyčíst citlivé údaje. Proti digitálním keyloggerům se lze bránit pomocí aktuálního antivirového programu. Existují ale také fyzické keyloggery, malá zařízení se dvěma USB porty. Do jednoho se připojí zařízení, které bude odposloucháváno a ten druhý se připojí do počítače. Zařízení si všechny vstupy ukládá do interního úložiště, nebo je přeposílá dál přes wifi.[^2]

Můj modul má v sobě integrovanou čtečku MIFARE RFID karet, ze kterých přečte zašifrované heslo, sám si ho dešifruje a výsledek pošle do počítače jako klávesnicový vstup. Je tedy také zranitelný vůči tomuto útoku. Když se ale zkombinují tyto dva způsoby zadávání hesla, může to útočníkovi ztížit získávání hesla. Například když klávesnicí uživatel zadá hes, mým modulem lo, a klávesnicí ještě 123, útočníkovi se zobrazí hes123 a lo odděleně a bude pro něj těžší získat tu správnou kombinaci.

## Způsob, jak zapnout počítač bez sehnutí

Umístí-li si uživatel modul na stůl, nebude se muset shýbat k zemi, aby si zapnul počítač.

## Zpříjemnění začátku pracovní doby

Modul po spuštění počítače přehraje náhodný zvuk z připojené micro SD karty. Uživatel si na ní může nahrát své oblíbené písničky a zlepšit si náladu ještě než se pustí do práce.

## Zobrazení času nebo data

Podle toho, co si uživatel zvolí, se na displeji může při nečinnosti zobrazovat buď aktuální datum, nebo čas. Nastavení data a času se aktualizuje na systémové hodnoty při každém spuštění počítače, není tedy třeba modul přenastavovat každých půl roku.

# Popis jednotlivých modulů

V této sekci najdete detailní popis fungování všech tří modulů i pythonového scriptu.

## Obrazovkový modul

Bla bla bla


# Nápad a první krůčky


Na tomto projektu jsem pracoval už na začátku roku 2021. Jednalo se sice tou dobou jen o jednoduché spojování drátků, ale už to by se dalo považovat za začátek. Bylo to červené tlačítko s krytkou a spínač na klíček, uchycený ve zmenšené kartonové krabičce od tužek. Dvěma kabely to bylo připojené na PW+ a PW-, které se sepnuly pouze když bylo otočeno klíčkem a zároveň bylo stlačené tlačítko.


SEQ Obrázek \* ARABIC 1 První prototyp zapínacího tlačítka, únor 2021

SEQ Obrázek \* ARABIC 2 Zapínání počítače pomocí spojení dvou drátků, srpen 2021 (snímek z videa)

Tenhle systém byl velmi neefektivní a ani jsem se nesnažil o žádný cable management. Navíc jsem tou dobou ještě neměl páječku a všechny spoje byly jen velmi pofidérně přivázané takže se často stalo, že jsem do kabelů kopl a něco vypojil, většinou přímo z modulu. Protože jsem líný a nechtělo se mi kabely přilepovat zespoda ke stolu, někdy začátkem srpna téhož roku jsem tlačítko i zámek odpojil a počítač zapínal manuálním spojením těch dvou drátků. Přestože mi první Arduino dorazilo z Číny jen o několik dní později, nespojil jsem si dvě a dvě dohromady, a ještě začátkem října jsem spojoval drátky.

## První použití Arduina

Nejpozději 15.10.2021 byla v provozu první verze tlačítka s Arduinem, konkrétně nějakou neoficiální verzí varianty Nano z Aliexpressu za 3.35$. Relativně velké červené tlačítko jsem vyměnil za generický push switch, protože jeho piny se akorát vešly do prototypovací destičky, pomocí které jsem všechno propojoval. Tato verze už využívala i malý jednobarevný displej s rozlišením 128x32 pixelů a úhlopříčkou 0.91 palce, připojený pomocí protokolu I²C. Na něm se po stisknutí tlačítka zobrazila uvítací hláška, a po zhruba 30 sekundách nečinnosti jednoduchý spořič obrazovky.


SEQ Obrázek \* ARABIC 3 Druhý prototyp zapínacího tlačítka, říjen 2021

SEQ Obrázek \* ARABIC 4 První pokusy s displejem, srpen 2021 (snímek z videa)

Tato verze ale také měla pár vad. Hlavní z nich bylo časté nezapnutí počítače po stisknutí tlačítka. Důvodem bylo moje nepochopení principu fungování PNP tranzistorů. Byl jsem v přesvědčení, že aby v PNP tranzistoru proudila elektřina z emitoru do kolektoru, musí být do báze přivedeno podobné napětí jako do emitoru a do kolektoru pak bude proudit elektřina z emitoru i báze. To ale není pravda. Aby to fungovalo, musíme do báze přivést nižší napětí tak, aby část proudu z emitoru šla do báze, čímž se umožní proudu projít i do kolektoru[^3]. Správně jsem měl mezi Arduino a bázi sériově zapojit ještě odpor, ale to jsem zjistil až později.

## Nedostatek RAM

Tou dobou jsem už začínal rozumět potenciálu, který ta malá věcička měla.
Objednal jsem si tedy kompatibilní čtečku micro SD karet a pár malých repráčků, abych mohl naimplementovat i přehrávání nějaké znělky při zapnutí počítače. Zde jsem ale narazil na další problém: grafická knihovna, kterou jsem používal, Adafruit GFX se totiž nevešla do operační paměti mého Arduina zároveň s knihovnou na čtení SD karet, a knihovnou na přehrávání audio souborů.

Nějakou dobu jsem si nevěděl rady, ale nakonec jsem se rozhodl si pořídit ještě jedno Arduino s větší RAM. Našel jsem si na Aliexpressu variantu Uno, která je o něco větší než Nano. Bohužel jsem si ale nepřečetl popis výrobku dostatečně pozorně a spletl jsem si velikost programové paměti s operační. Arduino Uno je totiž sice větší než Nano a specifikacemi se opravdu liší. Bohužel ale ne ve velikosti RAM, ta je u obou 2KB.

To ale nevadí, protože se mi podařilo propojit ty dvě Arduina tak, aby Uno ovládalo displej a při stisku tlačítka spustilo počítač, a Nano aby jen četlo audiosoubory z SD karty a pak je přehrávalo. Dokonce to ani nebylo tak těžké, jak by se mohlo zdát. Inspiroval jsem se komunikačním protokolem kalkulaček firmy Texas Instruments.

### Komunikace mezi kalkulačkami Texas Instruments


Společnost Texas Instruments nabízí mnoho různých kalkulaček s různými funkcemi a schopnostmi. Rozhodli se ale nechat tyto kalkulačky komunikovat jak mezi sebou, tak i s počítačem pomocí jen tří drátků. Aby spolu mohly komunikovat všechny jejich kalkulačky, bylo potřeba vyřešit problém synchronizace komunikace, aby obě kalkulačky stíhaly přijímat poslaná data a zároveň se zbytečně neomezovaly v přenosové rychlosti, i když jedna z nich může pracovat na nižší frekvenci. Řešením bylo nedovolit odesílateli poslat další bit, dokud příjemce nepotvrdí příjem.

V praxi to funguje tak, že jeden drátek je společná zem, druhý je signál 1 a třetí je signál 0. Zezačátku obě kalkulačky posílají do obou signálových pinů elektřinu, a jakmile se jedna z nich rozhodne posílat data, přestane posílat elektřinu do jednoho ze spojů podle toho, kterou hodnotu chce odeslat. Jakmile druhá kalkulačka zaregistruje tuto změnu, odpojí druhý signálový pin, čímž dává první kalkulačce signál, že zprávu přečetla. Obě potom opět připojí oba piny a odesílající kalkulačka může poslat další signál. Když jsou obě kalkulačky rychlé, komunikace probíhá rychle, pokud ne, rychlost komunikace se přizpůsobí té pomalejší[^4].

SEQ Obrázek \* ARABIC 5 Příklad komunikace mezi dvěma kalkulačkami TI
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

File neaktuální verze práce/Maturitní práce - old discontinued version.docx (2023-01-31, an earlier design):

MATURITNÍ PRÁCE

Obohacené zapínací tlačítko se zabezpečovací funkcionalitou

Studijní obor: IT

Třída: C4

Školní rok: 2022/2023

Jméno a příjmení: Vít Bezouška

Vedoucí práce: Radek Lampíř

Abstrakt

Abstract

Klíčová slova

Prohlašuji, že jsem tuto práci vypracoval(a) samostatně a použil(a) jsem literární prameny a informace, které cituji a uvádím v seznamu použité literatury a zdrojů informací.

V Praze dne …………. ……..……………………

jméno a příjmení

Obsah

Úvod 7

Nápad a první krůčky 8

První použití Arduina 8

Nedostatek RAM 9

Komunikace mezi kalkulačkami Texas Instruments 10

Komunikace mezi Arduiny 11

Shrnutí 11

Cíle práce 13

Zabezpečovací zařízení 13

Zamezit zapnutí počítače 13
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

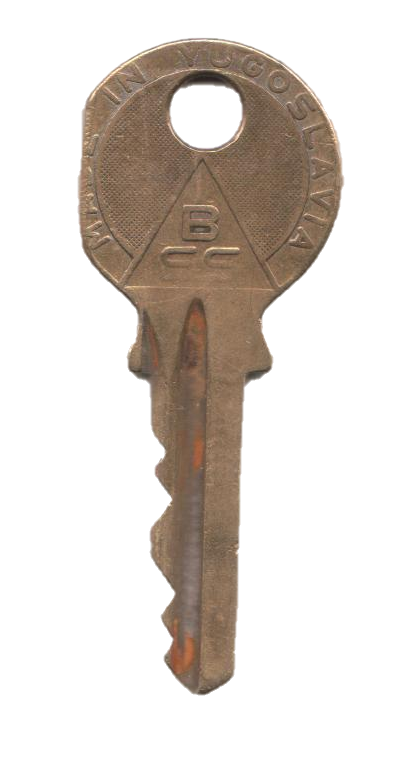
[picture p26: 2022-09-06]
fotky a schémata/concept art/cc0 key.png

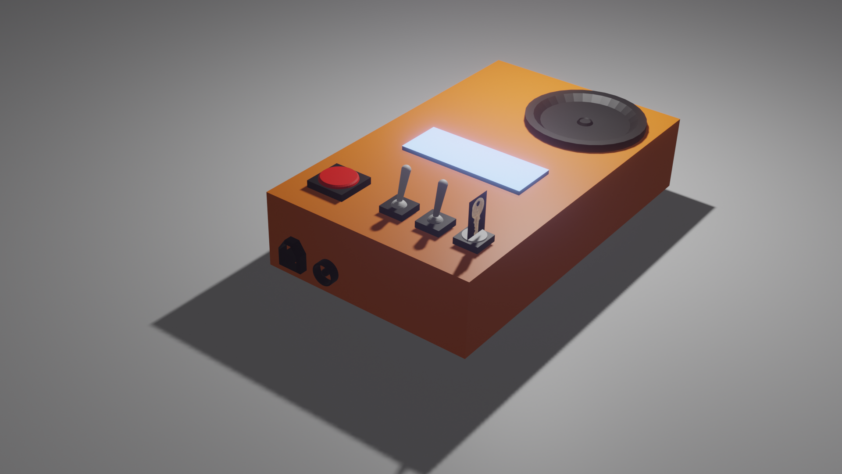
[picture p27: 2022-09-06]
fotky a schémata/concept art/concept art2.png

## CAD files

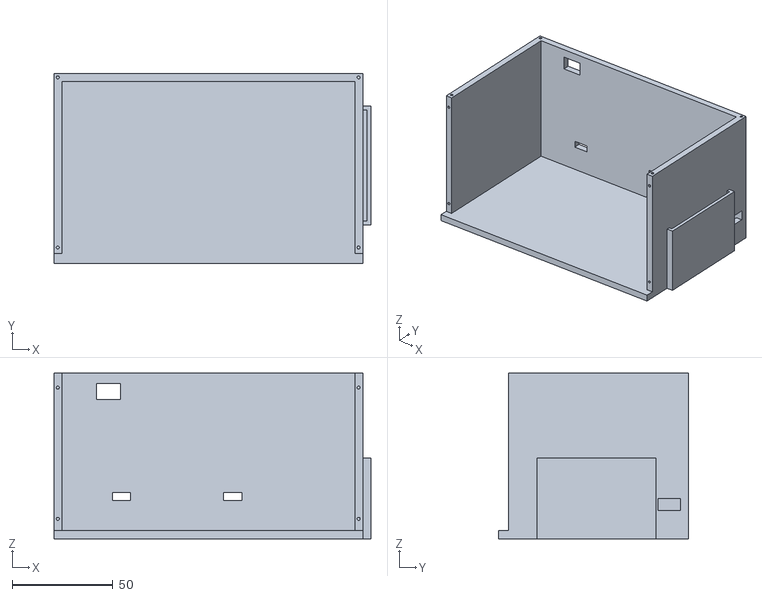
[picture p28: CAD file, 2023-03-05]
3d tisk/základ krabičky.stl
157.0 x 94.0 x 82.0

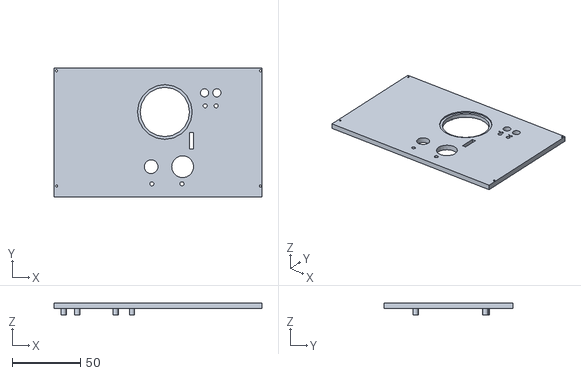
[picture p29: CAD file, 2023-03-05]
3d tisk/poklop krabičky.stl
152.0 x 94.0 x 9.10

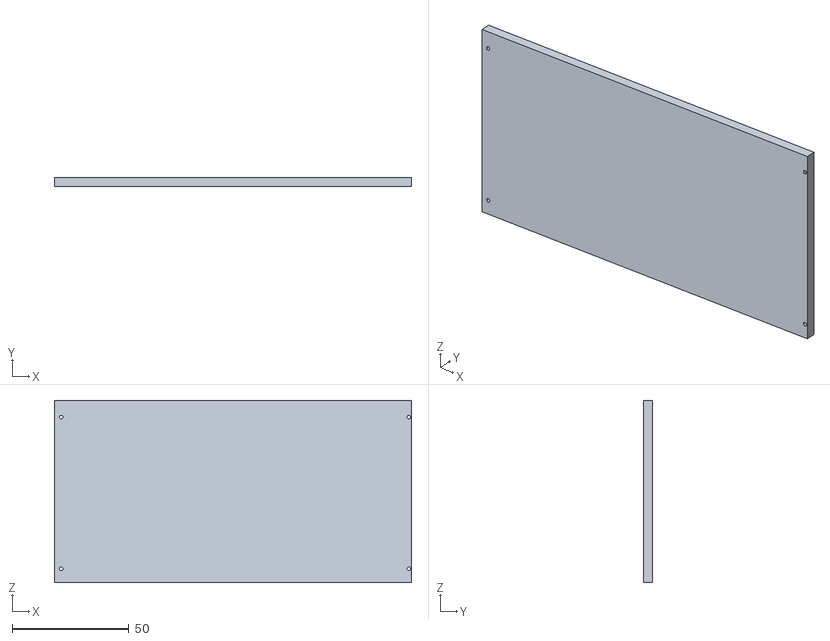
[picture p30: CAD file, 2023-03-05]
3d tisk/panel krabičky.stl
153.0 x 4.00 x 78.0

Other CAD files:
fotky a schémata/concept art/concept art.blend

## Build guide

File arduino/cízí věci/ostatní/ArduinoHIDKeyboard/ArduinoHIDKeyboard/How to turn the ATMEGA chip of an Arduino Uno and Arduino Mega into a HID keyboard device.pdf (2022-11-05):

# How to turn the ATMEGA chip of an Arduino Uno and Arduino Mega into a HID

keyboard device.

Eward Hage

Interaction design

Hogeschool voor de kunsten Utrecht

In this tutorial I shall explain how you can turn your Arduino chip into a HID keyboard device. This is done by updating the Firmware on your chip with a special firmware trick. After some research and not supported software I have put in an ArduinoHIDKeyboard.rar file with this PDF for all the requirements needed to perform this action.

NOTE: This is also a very basic Arduino coding tutorial, you can make it as advanced as you like

Examples of uses:

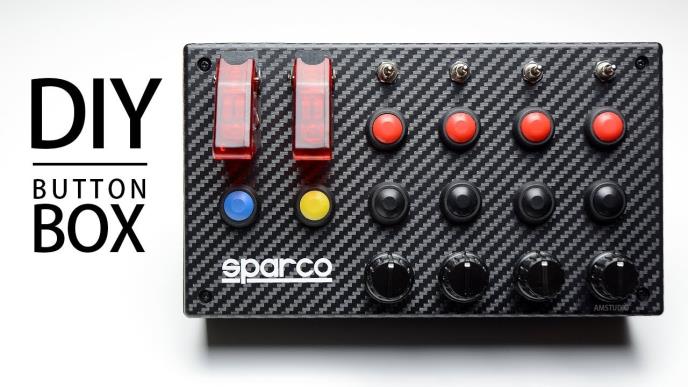
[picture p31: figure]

https://www.youtube.com/watch?v=Z7Sc4MJ8RPM

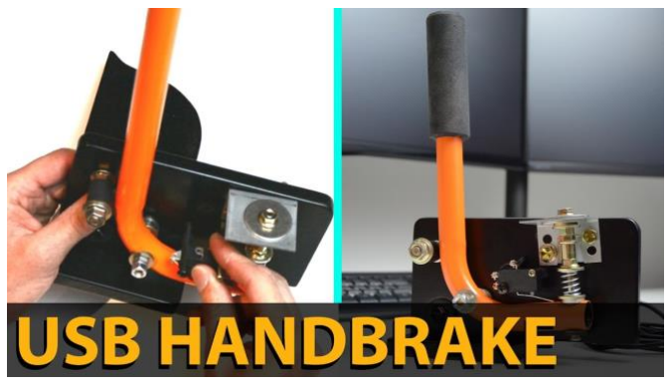
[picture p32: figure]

https://www.youtube.com/watch?v=NQaogjVaQek

Custom controllers compatible with all games on PC, Xbox or PlayStation if keyboard is supported.

But basically you can make all sorts of controller stuff with this trick!

### Contents

## Setup of the Arduino

The setup of the Arduino hardware is the same as we are used to developing with the Arduino platform. For this example we use 4 push buttons as seen in Pic 1.

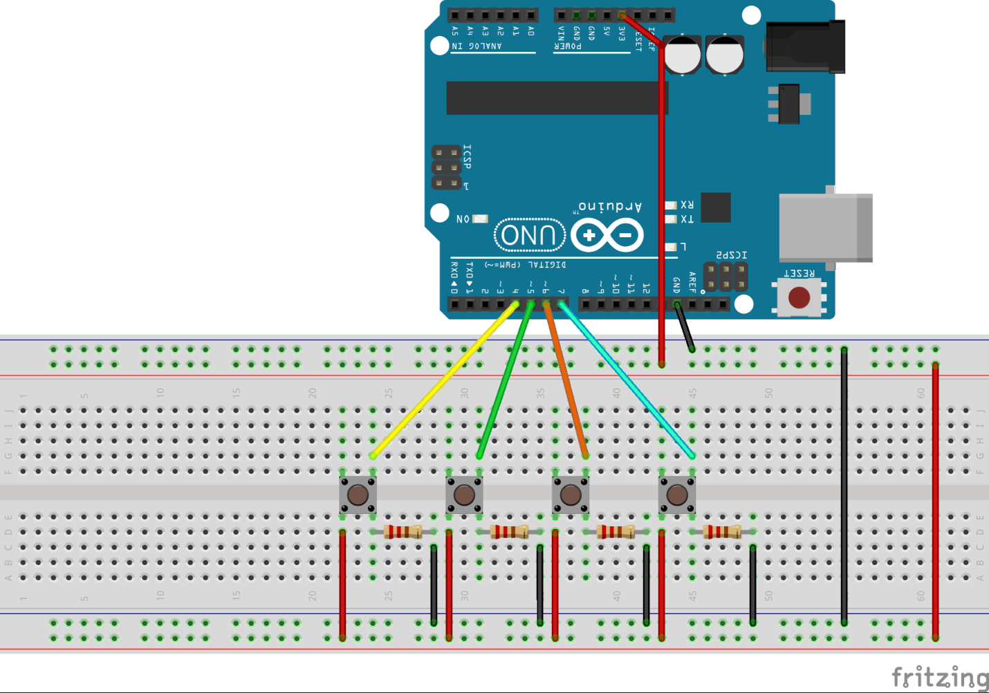
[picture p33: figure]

Pic 1. The basic setup of the Arduino for this example. (This can also be done with the Arduino Mega if more pin inputs are required) Note that we use the 3.3v of the Arduino as the input current of the pushbuttons onto the Digital-pins. The resistors used for this example are 1k ohm resistors.

## How to code a key press onto the Arduino

Coding is done using the Arduino IDE, there are no extra special requirements needed except for the Output requirements of a HID device.

### Step 1) Initialize a buffer

First we initialize a keyboard buffer, this is required for the Arduino to send a bit register as a HID Keyboard.

### Step 2) Define pins

Define the pins of the Arduino, you can also use (const int PIN_W = 4;) but I prefer the #define method.

### Step 3) Void Setup() and Baud rates

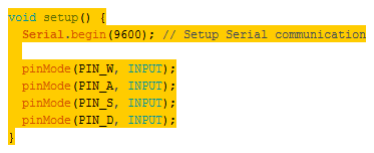
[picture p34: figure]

Write the setup function, as with every Arduino code project the setup is pretty much the same except that setting the Baud rate and serial communication with the (Serial.begin(9600)) function is required for the Arduino to communicate with your computer.

The Baud rate can vary between (insert baud rates) this depends on how quick you want your bits to be send. More info on Baud rate this reference link: https://www.arduino.cc/reference/en/language/functions/communication/serial/begin/

Step 4) Write a key release function.

Write an end buffer method to send a bit when button is released, this step is required to end the data stream of the HID keyboard. For this example we send the key code through buf[2] so we need to reset them to 0 when the button on the Arduino is released.

Note: Without this step you’re HID keyboard can start sending button inputs but it will never stop sending bits until the HID keyboard (Arduino) USB is unplugged.

### Step 5) Writing a key press in the Loop()

This step is done in the Loop() function to be updated every cycle the Arduino get through checking if a button is pressed.

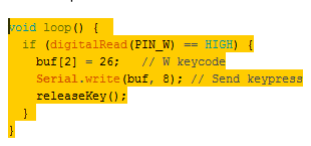
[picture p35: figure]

To send a key press we need to access the keyboard buffer, and put in our key code value. See Pic 2 for Key codes.

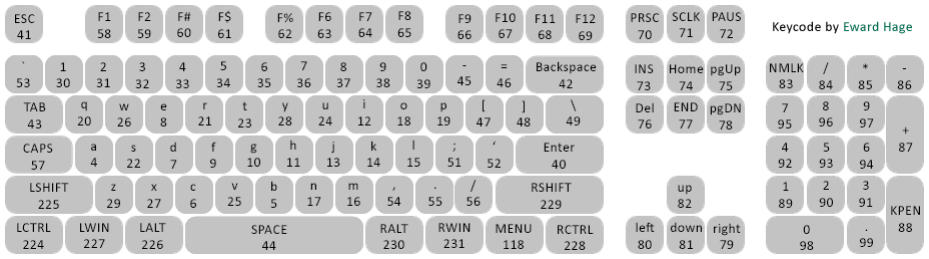
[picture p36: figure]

Pic 2 Key code image.

### Useful tip for Debugging your device

For debugging purposes I recommend putting a Serial.println(“W pressed”) after the Serial.write(buf,8) Before flashing the Arduino with FLIP. This way, with the serial monitor of the Arduino IDE you can debug in the Arduino environment.

NOTE: Remove the Serial.println(“W pressed”) before updating the firmware to the keyboard. Serial.println function can cause interference with the Serial.write thus making the Serial communication not working.

### Example code

uint8_t buf[8] = { 0 }; //Keyboard report buffer #define PIN_W 4 // Pin for w
#define PIN_A 5 // Pin for a

#define PIN_S 6 // Pin for s

#define PIN_D 7 // Pin for d

void setup() {
Serial.begin(9600); // Setup Serial communication

//Set pinmode of Input pins
pinMode(PIN_W, INPUT);
pinMode(PIN_A, INPUT);
pinMode(PIN_S, INPUT);
pinMode(PIN_D, INPUT);
}

void loop() {
//When button representing W is pressed if (digitalRead(PIN_W) == HIGH) { buf[2] = 26; // W keycode
Serial.write(buf, 8); // Send keypress releaseKey();
}

//When button representing A is pressed if (digitalRead(PIN_A) == HIGH) { buf[2] = 4; // A keycode
Serial.write(buf, 8); // Send keypress releaseKey();
}

//When button representing S is pressed if (digitalRead(PIN_S) == HIGH) { buf[2] = 22; // S keycode
Serial.write(buf, 8); // Send keypress releaseKey();
}

//When button representing D is pressed if (digitalRead(PIN_D) == HIGH) { buf[2] = 7; // D keycode
Serial.write(buf, 8); // Send keypress releaseKey();
}
}
// Function for Key Release void releaseKey()
{
buf[0] = 0;
buf[2] = 0;
Serial.write(buf, 8); // Send Release key }

## Installing and Setting up FLIP 3.4.7

Flip is a firmware hex file pusher developed by ATMEL for their chipsets. They do not support flip anymore but it works like a charm.

### Step 1) Install and open FLIP

To install FLIP please install JRE - Flip Installer - 3.4.7.112.exe provided in the ArduinoHIDKeyboard.rar

Then start it up.

Note: When starting up you get the error "AtLibUsbDfu.dll not found" you have to install a driver. Here is a solution made by MDGrein link: https://www.youtube.com/watch?v=KQ9BjKjGnIc

Open up FLIP

### Step 2) Chose the device Chipset

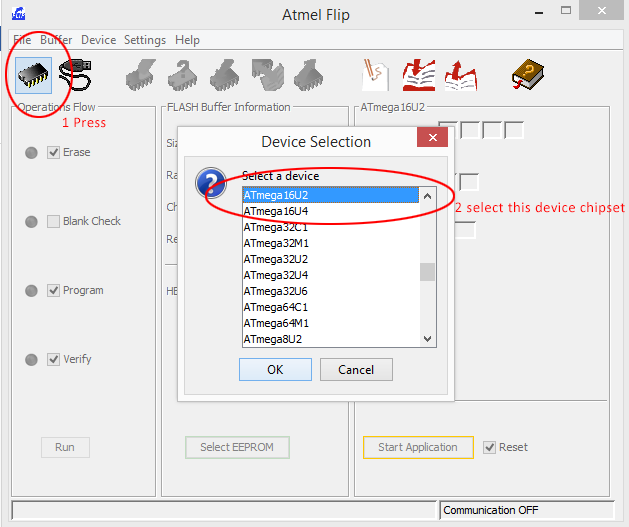
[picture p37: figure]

Press the Highlighted chip button, then Select ATmega16u2 and then the button OK. As this is the chipset for the Arduino Uno R3 and the Arduino Mega R3.

And now you are done with setting up flip and we can go to the Next step of Flashing the Arduino.

## How to flash the Arduino using FLIP 3.4.7

### Step 1) Upload your Arduino code

Upload your code or the examplecode given by pressing the upload button in the Arduino IDE

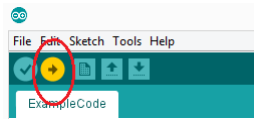
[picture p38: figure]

You will get a message at the bottom from the Arduino IDE saying done Uploading

Note: if uploading fails
Check 1 COM port under Tools>port if none is available unplug and replug USB or check device manager.
Check 2 if you have the correct board selected in Tools>board.

### Step 2) Put Arduino onto DFU mode

To put the Arduino in the DFU (Device Firmware Update) mode, so that FLIP can access the Firmware on the Arduino Chip.

More info on this reference link: https://www.arduino.cc/en/Hacking/DFUProgramming8U2

To do this short the 2 ICSP2 pins as done in the image

Example for the Arduino Uno

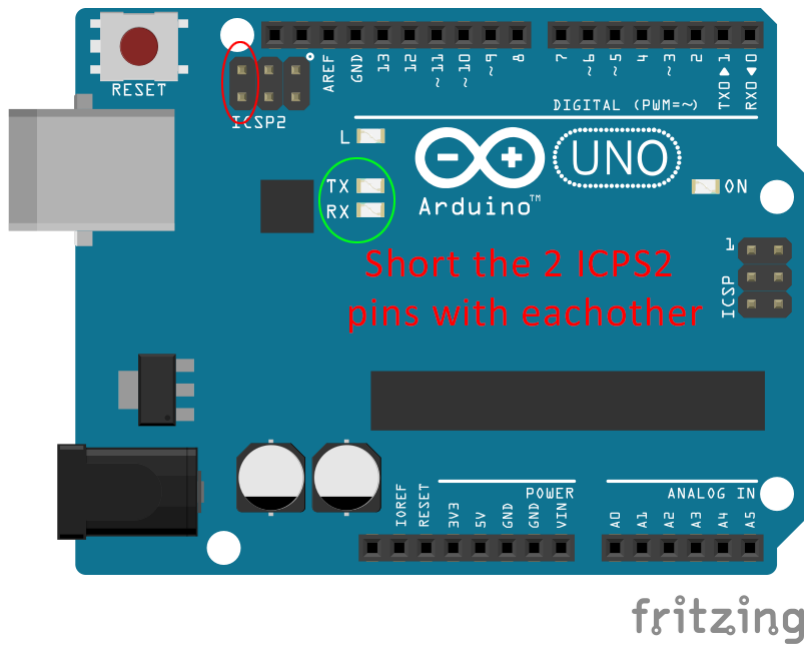
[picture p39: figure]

Example for the Arduino Mega

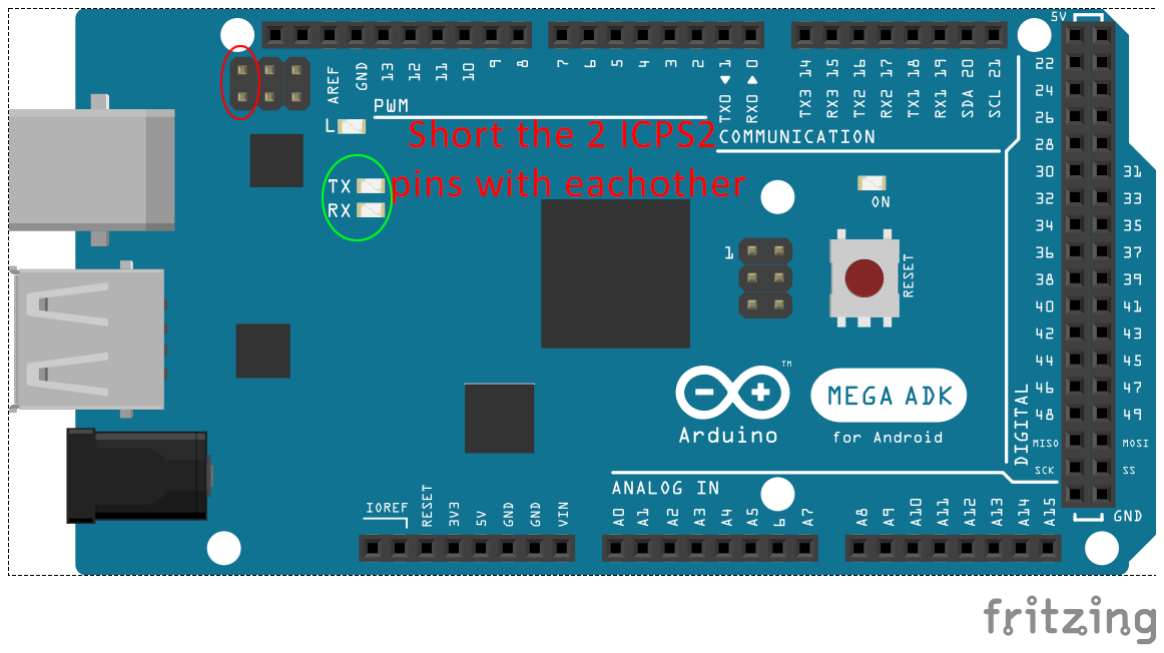
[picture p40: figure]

In both case the TX and RX led in the green circle will flash and you will hear a USB disconnect sound, NOTE: if not unplug and replug the Arduino USB and repeat the process of shorting the 2 ICSP2 pins.

### Step 3) Open FLIP USB

Press the USB icon in FLIP and then open.

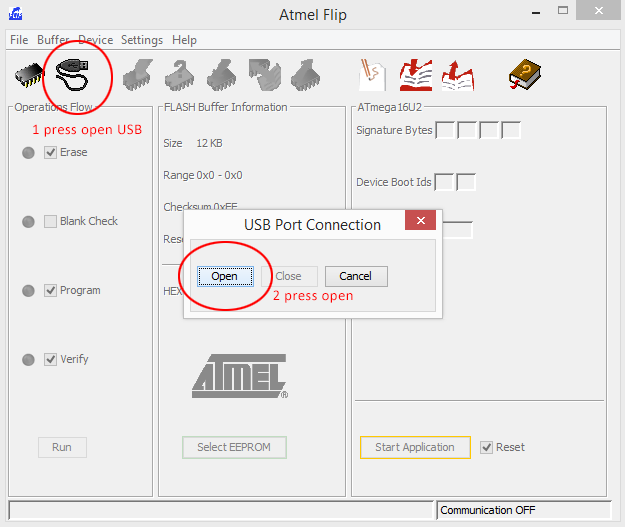
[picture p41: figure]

### Step 4) Parse the firmware HEX

You will see at the bottom USB ON, this is that the Arduino is connected through DFU Mode.

Select the Arduino-keyboard.hex file,

or if you want your Arduino Back select Arduino-usbserial-uno.hex

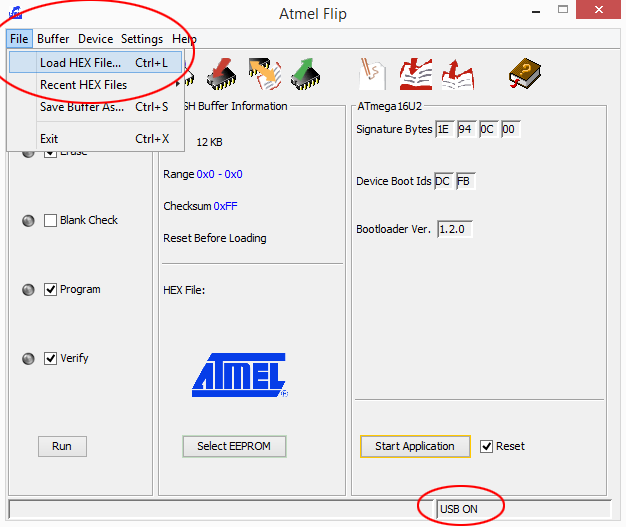
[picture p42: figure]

And press Run (NOT START APPLICATION)!

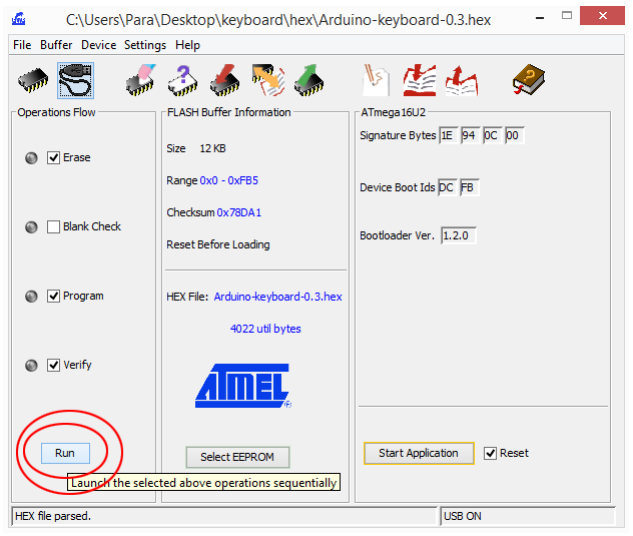
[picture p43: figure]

### Step 5) Unplug and replug USB

You will see this all in green if not close FLIP and return to step 3 Open FLIP USB

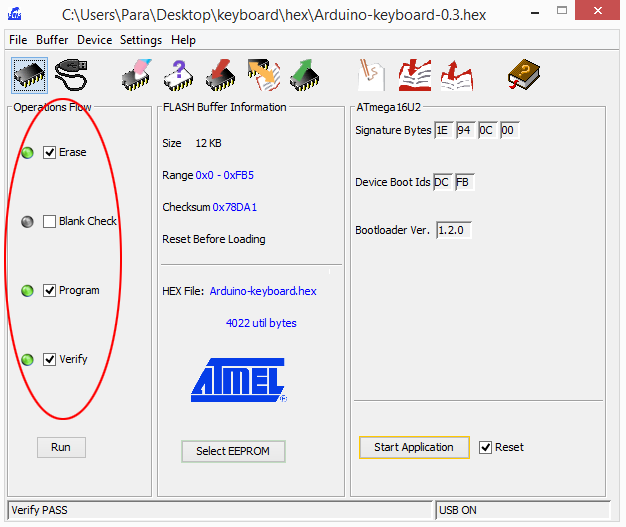
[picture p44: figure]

Then unplug and replug your new Keyboard device.

How to check if the flash worked.

From now on the Arduino is a HID Keyboard Congratulations!

The only thing now is that the Arduino IDE does not support your Arduino anymore. So to check if your HID keyboard works we open Notepad, or any other text editor.

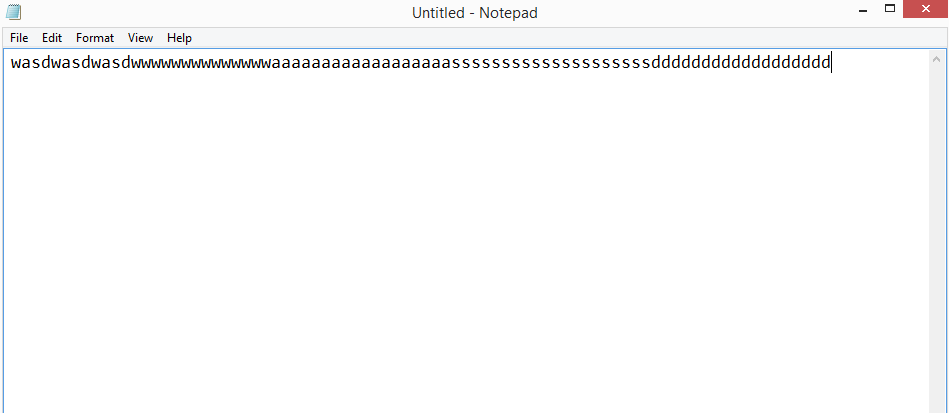
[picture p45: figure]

You can also play games with your keyboard or put volume up and down with macro’s you name it you have the power to do it.

## How to flash the HID Keyboard into a Arduino using FLIP 3.4.7

But Eward I want my Arduino back! Ok ok calm down.

You can do that by repeating the steps of chapter how to flash you Arduino, only then in step 4 chose Arduino-usbserial-uno.hex instead of arduino-keyboard.hex

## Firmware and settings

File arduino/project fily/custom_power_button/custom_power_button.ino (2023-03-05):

/**************************************************************************
  This is an example for our Monochrome OLEDs based on SSD1306 drivers

  Pick one up today in the adafruit shop!
  ------> http://www.adafruit.com/category/63_98

  This example is for a 128x32 pixel display using I2C to communicate
  3 pins are required to interface (two I2C and one reset).

  Adafruit invests time and resources providing this ;open
  source code, please support Adafruit and open-source
  hardware by purchasing products from Adafruit!

  Written by Limor Fried/Ladyada for Adafruit Industries,
  with contributions from the open source community.
  BSD license, check license.txt for more information
  All text above, and the splash screen below must be
  included in any redistribution.
 **************************************************************************/

#include <Wire.h>
#include <Adafruit_GFX.h>
#include <Adafruit_SSD1306.h>

#define SCREEN_WIDTH 128 // OLED display width, in pixels
#define SCREEN_HEIGHT 32 // OLED display height, in pixels

// Declaration for an SSD1306 display connected to I2C (SDA, SCL pins)
// The pins for I2C are defined by the Wire-library.
// On an arduino UNO:       A4(SDA), A5(SCL)
// On an arduino MEGA 2560: 20(SDA), 21(SCL)
// On an arduino LEONARDO:   2(SDA),  3(SCL), ...
#define OLED_RESET     -1 // Reset pin # (or -1 if sharing Arduino reset pin)
#define SCREEN_ADDRESS 0x3C ///< See datasheet for Address; 0x3D for 128x64, 0x3C for 128x32
Adafruit_SSD1306 display(SCREEN_WIDTH, SCREEN_HEIGHT, &Wire, OLED_RESET);

// #define NUMFLAKES     10 // Number of snowflakes in the animation example

#define LOGO_HEIGHT   16
#define LOGO_WIDTH    16

#define SERIAL_BUFFER_SIZE 16

static const unsigned char big_chester [] PROGMEM = {
  0x00, 0x00, 0x00, 0x00, 0x00, 0x00, 0x00, 0x00, 0x00, 0x00, 0x01, 0xe0, 0x07, 0x80, 0x00, 0x02,
  0x1f, 0xf8, 0x40, 0x00, 0x02, 0xd0, 0x0b, 0x40, 0x00, 0x02, 0xd0, 0x0b, 0x40, 0x00, 0x02, 0x10,
  0x08, 0x60, 0x00, 0x05, 0xe0, 0x07, 0x98, 0x00, 0x08, 0x00, 0x00, 0x04, 0x00, 0x10, 0x00, 0x00,
  0x02, 0x00, 0x20, 0x00, 0x00, 0x02, 0x00, 0x20, 0x00, 0x00, 0x01, 0x00, 0x30, 0x00, 0x00, 0x01,
  0x00, 0x5c, 0x00, 0x00, 0x07, 0x00, 0x4b, 0xc0, 0x00, 0x3b, 0x00, 0x24, 0x3f, 0xff, 0xc5, 0x00,
  0x23, 0xe4, 0x08, 0x8a, 0x00, 0x10, 0x27, 0xf8, 0xf2, 0x00, 0x08, 0x24, 0x08, 0x84, 0x00, 0x04,
  0x18, 0x08, 0x88, 0x00, 0x02, 0x00, 0x07, 0x10, 0x00, 0x01, 0xf0, 0x00, 0x20, 0x00, 0x02, 0x0e,
  0x00, 0x40, 0x00, 0x04, 0x01, 0xff, 0x80, 0x00, 0x08, 0x00, 0x00, 0x80, 0x00, 0x10, 0x00, 0x00,
  0x80, 0x00, 0x20, 0x00, 0x00, 0x40, 0x00, 0x20, 0xff, 0x80, 0x40, 0x00, 0x27, 0x00, 0x40, 0x40,
  0x00, 0x18, 0x00, 0x3e, 0x40, 0x00, 0x00, 0x00, 0x01, 0x80, 0x00, 0x00, 0x00, 0x00, 0x00, 0x00
};

const unsigned char amogus [][20] PROGMEM = {
  {
    0x00, 0x00, 0x7e, 0x00, 0x91, 0x00, 0xa1, 0x00, 0x40, 0x80, 0x40, 0x80, 0x26, 0x80, 0x19, 0x00,
    0x10, 0x00, 0x00, 0x00
  },
  {
    0x07, 0x00, 0x78, 0x80, 0xa0, 0x40, 0xc0, 0x40, 0x40, 0x40, 0x20, 0x40, 0x22, 0x80, 0x15, 0x00,
    0x18, 0x00, 0x00, 0x00
  },
  {
    0x00, 0x00, 0x7e, 0x00, 0x89, 0x80, 0x90, 0x40, 0xe0, 0x40, 0x20, 0x40, 0x20, 0x80, 0x17, 0x00,
    0x18, 0x00, 0x00, 0x00
  },
  {
    0x00, 0x00, 0x38, 0x00, 0x47, 0x00, 0x48, 0x80, 0x50, 0x40, 0x20, 0x40, 0x20, 0x40, 0x20, 0x80,
    0x1f, 0x00, 0x00, 0x00
  },
  {
    0x00, 0x00, 0x3c, 0x00, 0x47, 0x00, 0xbc, 0x80, 0x40, 0x40, 0x40, 0x80, 0x40, 0x80, 0x67, 0x00,
    0x18, 0x00, 0x00, 0x00
  },
  {
    0x00, 0x00, 0x3e, 0x00, 0xe1, 0x00, 0xc0, 0x80, 0x40, 0x80, 0x40, 0x80, 0x22, 0x80, 0x25, 0x00,
    0x18, 0x00, 0x00, 0x00
  }
};

const unsigned char nano [] PROGMEM = {
  // 'NANO, 11x18px
  0x1f, 0x00, 0xf1, 0xe0, 0x8e, 0x20, 0xa0, 0xa0, 0x80, 0x20, 0xa0, 0xa0, 0x80, 0x20, 0xa0, 0xa0,
  0x80, 0x20, 0xa0, 0xa0, 0x80, 0x20, 0xa0, 0xa0, 0x8a, 0x20, 0xa0, 0xa0, 0x8e, 0x20, 0xae, 0xa0,
  0x80, 0x20, 0xff, 0xe0
};

// 'notready warn', 13x15px with alpha shadow
const unsigned char notready_warn [] PROGMEM = {
  0x00, 0x00, 0x00, 0x00, 0x02, 0x00, 0x05, 0x00, 0x05, 0x00, 0x08, 0x80, 0x0a, 0x80, 0x12, 0x40,
  0x12, 0x40, 0x20, 0x20, 0x22, 0x20, 0x40, 0x10, 0x7f, 0xf0, 0x00, 0x00, 0x00, 0x00
};

const unsigned char notready_warn_shadow [] PROGMEM = {
  0x00, 0x00, 0x02, 0x00, 0x07, 0x00, 0x07, 0x00, 0x0f, 0x80, 0x0f, 0x80, 0x1f, 0xc0, 0x1f, 0xc0,
  0x3f, 0xe0, 0x7f, 0xf0, 0x7f, 0xf0, 0x7f, 0xf0, 0x7f, 0xf0, 0x7f, 0xf0, 0x00, 0x00
};

// 'PC', 31x21px
const unsigned char PC [] PROGMEM = {
  0x00, 0x00, 0x00, 0x00, 0x00, 0x00, 0x7f, 0xfc, 0x00, 0x00, 0x40, 0x04, 0x00, 0x00, 0x40, 0x04,
  0x7f, 0xff, 0xc0, 0x04, 0x40, 0x00, 0x5f, 0xf4, 0x40, 0x00, 0x50, 0x14, 0x40, 0x00, 0x5f, 0xf4,
  0x40, 0x00, 0x40, 0x04, 0x40, 0x00, 0x40, 0x04, 0x40, 0x00, 0x40, 0x04, 0x40, 0x00, 0x40, 0x04,
  0x40, 0x00, 0x40, 0x04, 0x40, 0x00, 0x40, 0x04, 0x40, 0x00, 0x40, 0x04, 0x40, 0x00, 0x40, 0x04,
  0x7f, 0xff, 0xc7, 0xc4, 0x00, 0x20, 0x40, 0x04, 0x01, 0xfc, 0x40, 0x04, 0x00, 0x00, 0x7f, 0xfc,
  0x00, 0x00, 0x00, 0x00
};

// 'unresponsive sleep zzz', 11x11px
const unsigned char  zzz [] PROGMEM = {
  0x00, 0x00, 0x01, 0xc0, 0x00, 0x40, 0x00, 0x80, 0x0d, 0x00, 0x05, 0xc0, 0x08, 0x00, 0x6c, 0x00,
  0x20, 0x00, 0x30, 0x00, 0x00, 0x00
};

const unsigned char  zzz_shadow [] PROGMEM = {
  0x03, 0xe0, 0x03, 0xe0, 0x03, 0xe0, 0x1f, 0xe0, 0x1f, 0xe0, 0x1f, 0xe0, 0xff, 0xe0, 0xfe, 0x00,
  0xfe, 0x00, 0x78, 0x00, 0x78, 0x00
};

// 'wait clock', 11x11px
const unsigned char  wait [] PROGMEM = {
  0x00, 0x00, 0x1f, 0x00, 0x20, 0x80, 0x44, 0x40, 0x44, 0x40, 0x46, 0x40, 0x40, 0x40, 0x40, 0x40,
  0x20, 0x80, 0x1f, 0x00, 0x00, 0x00
};
const unsigned char  wait_shadow [] PROGMEM = {
  0x3f, 0x80, 0x7f, 0xc0, 0xff, 0xe0, 0xff, 0xe0, 0xff, 0xe0, 0xff, 0xe0, 0xff, 0xe0, 0xff, 0xe0,
  0xff, 0xe0, 0x7f, 0xc0, 0x3f, 0x80
};

// 'err', 11x11px
const unsigned char  err [] PROGMEM = {
  0x00, 0x00, 0x1f, 0x00, 0x20, 0x80, 0x40, 0x40, 0x40, 0x40, 0x5f, 0x40, 0x40, 0x40, 0x40, 0x40,
  0x20, 0x80, 0x1f, 0x00, 0x00, 0x00
};

const unsigned char  err_shadow [] PROGMEM = {
  0x3f, 0x80, 0x7f, 0xc0, 0xff, 0xe0, 0xff, 0xe0, 0xff, 0xe0, 0xff, 0xe0, 0xff, 0xe0, 0xff, 0xe0,
  0xff, 0xe0, 0x7f, 0xc0, 0x3f, 0x80
};

// 'check', 10x11px
const unsigned char  checkmark [] PROGMEM = {
  0x00, 0x00, 0x00, 0x80, 0x01, 0x80, 0x01, 0x00, 0x03, 0x00, 0x02, 0x00, 0x66, 0x00, 0x34, 0x00,
  0x1c, 0x00, 0x08, 0x00, 0x00, 0x00
};

// 'button pushed big', 32x32px
const unsigned char  button_pushed_big [] PROGMEM = {
  0x00, 0x00, 0x00, 0x00, 0x00, 0x00, 0x10, 0x20, 0x00, 0x00, 0x10, 0x20, 0x00, 0x00, 0x10, 0x20,
  0x00, 0x00, 0x10, 0x20, 0x01, 0x00, 0x10, 0x20, 0x01, 0x00, 0x10, 0x20, 0x01, 0x00, 0x10, 0x20,
  0x01, 0x00, 0x20, 0x20, 0x01, 0x00, 0x20, 0x20, 0x01, 0x00, 0x60, 0x60, 0x01, 0x00, 0x60, 0x40,
  0x09, 0x20, 0xa0, 0x40, 0x05, 0x41, 0x20, 0x40, 0x03, 0x82, 0x20, 0x40, 0x01, 0x04, 0x20, 0x80,
  0x00, 0x08, 0x40, 0x80, 0x00, 0x10, 0x81, 0x00, 0x00, 0x23, 0x02, 0x00, 0x00, 0x5c, 0x02, 0x00,
  0x00, 0x40, 0x04, 0x00, 0x00, 0x40, 0x08, 0x00, 0x00, 0x3f, 0xf0, 0x00, 0x00, 0x00, 0x00, 0x00,
  0x00, 0x00, 0x00, 0x00, 0x00, 0x00, 0x00, 0x00, 0x00, 0x00, 0x00, 0x00, 0x07, 0xff, 0xff, 0xe0,
  0x04, 0x00, 0x00, 0x20, 0x04, 0x00, 0x00, 0x20, 0x3f, 0xff, 0xff, 0xfc, 0x00, 0x00, 0x00, 0x00
};

const uint8_t __comic15pt7bBitmaps[] PROGMEM = {
  0xDF, 0xFF, 0xFF, 0xFF, 0xFF, 0xFF, 0xFF, 0x01, 0xBE, 0xC6, 0xC7, 0xC7,
  0xC7, 0xC7, 0xC7, 0xC7, 0xC7, 0xC6, 0x00, 0x60, 0x18, 0x00, 0x60, 0x38,
  0x00, 0xE0, 0x38, 0x00, 0xE0, 0x30, 0x00, 0xE0, 0x70, 0x3F, 0xFF, 0xFF,
  0x3F, 0xFF, 0xFF, 0x3F, 0xFF, 0xFF, 0x01, 0x80, 0xE0, 0x03, 0x80, 0xE0,
  0x03, 0x80, 0xC0, 0x03, 0x01, 0xC0, 0x07, 0x01, 0xC0, 0x7F, 0xFF, 0xFC,
  0xFF, 0xFF, 0xFE, 0x7F, 0xFF, 0xFE, 0x0E, 0x03, 0x80, 0x0E, 0x03, 0x80,
  0x0C, 0x07, 0x00, 0x1C, 0x07, 0x00, 0x1C, 0x07, 0x00, 0x18, 0x06, 0x00,
  0x00, 0xC0, 0x01, 0xC0, 0x01, 0xC0, 0x01, 0xC0, 0x03, 0xF8, 0x07, 0xFE,
  0x1F, 0xFE, 0x1D, 0xCE, 0x39, 0xC0, 0x39, 0xC0, 0x79, 0xC0, 0x79, 0xC0,
  0x3D, 0xC0, 0x3F, 0xF0, 0x1F, 0xFC, 0x07, 0xFE, 0x01, 0xDF, 0x01, 0xC7,
  0x01, 0xC7, 0x01, 0xC7, 0x01, 0xC7, 0x61, 0xCF, 0xF9, 0xDE, 0x7F, 0xFE,
  0x7F, 0xFC, 0x1F, 0xF0, 0x01, 0xC0, 0x01, 0xC0, 0x01, 0xC0, 0x01, 0xC0,
  0x00, 0xC0, 0x00, 0x07, 0x00, 0xE0, 0x38, 0x1F, 0xC3, 0x81, 0xC6, 0x1C,
  0x0E, 0x39, 0xC0, 0x61, 0xCE, 0x03, 0x8E, 0x60, 0x0C, 0x67, 0x00, 0x7F,
  0x30, 0x01, 0xE3, 0x80, 0x00, 0x18, 0x00, 0x01, 0xC0, 0x00, 0x0C, 0x00,
  0x00, 0xE0, 0x00, 0x07, 0x0F, 0x00, 0x71, 0xFE, 0x03, 0x8E, 0x30, 0x38,
  0xE1, 0xC1, 0xC7, 0x0E, 0x1C, 0x38, 0x70, 0xE0, 0xC3, 0x06, 0x07, 0xF0,
  0x30, 0x0F, 0x00, 0x00, 0xE0, 0x00, 0xF8, 0x00, 0xEE, 0x00, 0x77, 0x00,
  0x33, 0x80, 0x19, 0xC0, 0x0F, 0xC0, 0x07, 0xE0, 0x03, 0xE0, 0x03, 0xE0,
  0x03, 0xF0, 0x03, 0xDC, 0x63, 0x8E, 0x33, 0x83, 0xB9, 0x81, 0xDD, 0xC0,
  0x7E, 0xE0, 0x1E, 0x70, 0x0F, 0x38, 0x07, 0x8E, 0x0F, 0xC7, 0xFF, 0xF1,
  0xFF, 0x18, 0x3E, 0x0E, 0x00, 0x03, 0xDF, 0xFF, 0xF0, 0x03, 0x0F, 0x1E,
  0x1C, 0x38, 0x38, 0x70, 0x70, 0x60, 0xE0, 0xE0, 0xE0, 0xE0, 0xE0, 0xC0,
  0xC0, 0xC0, 0xE0, 0xE0, 0xE0, 0xE0, 0xE0, 0x70, 0x70, 0x38, 0x3C, 0x1E,
  0x0F, 0x07, 0xC0, 0xE0, 0xF0, 0x78, 0x38, 0x1C, 0x1C, 0x0E, 0x0E, 0x0E,
  0x06, 0x07, 0x07, 0x07, 0x07, 0x07, 0x07, 0x07, 0x07, 0x06, 0x0E, 0x0E,
  0x0E, 0x1C, 0x1C, 0x38, 0xF8, 0xF0, 0xC0, 0x06, 0x00, 0x30, 0x01, 0x81,
  0x8C, 0x0F, 0x7F, 0x3F, 0xFC, 0x3F, 0xC3, 0xF0, 0x3F, 0xC3, 0xCF, 0x18,
  0x38, 0x00, 0xC0, 0x06, 0x00, 0xE0, 0x0E, 0x00, 0xE0, 0x0E, 0x0F, 0xFE,
  0xFF, 0xFF, 0xFF, 0x0E, 0x00, 0xE0, 0x0E, 0x00, 0xE0, 0x06, 0x00, 0x37,
  0x76, 0xEC, 0xC0, 0xFF, 0x7F, 0xFF, 0xC0, 0x6E, 0xE6, 0x00, 0x38, 0x01,
  0xC0, 0x1C, 0x00, 0xE0, 0x06, 0x00, 0x70, 0x03, 0x80, 0x38, 0x01, 0xC0,
  0x1C, 0x00, 0xE0, 0x0E, 0x00, 0x70, 0x07, 0x00, 0x38, 0x03, 0x80, 0x1C,
  0x01, 0xC0, 0x0E, 0x00, 0xE0, 0x07, 0x00, 0x30, 0x03, 0x80, 0x18, 0x00,
  0x07, 0xE0, 0x0F, 0xF0, 0x1F, 0xF8, 0x3C, 0x3C, 0x78, 0x1E, 0x70, 0x0E,
  0xE0, 0x0E, 0xE0, 0x07, 0xE0, 0x07, 0xE0, 0x07, 0xE0, 0x07, 0xE0, 0x07,
  0xE0, 0x07, 0xE0, 0x06, 0xE0, 0x0E, 0xE0, 0x0E, 0x70, 0x0E, 0x70, 0x1C,
  0x3C, 0x3C, 0x3F, 0xF8, 0x1F, 0xF0, 0x07, 0xE0, 0x06, 0x0F, 0x0F, 0x8F,
  0xCF, 0xE3, 0x70, 0x38, 0x1C, 0x0E, 0x07, 0x03, 0x81, 0x80, 0xC0, 0x60,
  0x70, 0x38, 0x0C, 0x06, 0x03, 0x0F, 0xFF, 0xFB, 0xFC, 0x07, 0xC0, 0x7F,
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
};

const GFXglyph __comic15pt7bGlyphs[] PROGMEM = {
  {     0,   0,   0,   9,    0,    1 },   // 0x20 ' '
  {     0,   3,  24,   7,    2,  -22 },   // 0x21 '!'
  {     9,   8,   9,  12,    2,  -21 },   // 0x22 '"'
  {    18,  24,  22,  24,    0,  -21 },   // 0x23 '#'
  {    84,  16,  31,  20,    1,  -25 },   // 0x24 '$'
  {   146,  21,  23,  24,    2,  -22 },   // 0x25 '%'
  {   207,  17,  24,  19,    1,  -21 },   // 0x26 '&'
  {   258,   3,   7,  11,    4,  -21 },   // 0x27 '''
  {   261,   8,  29,  11,    2,  -22 },   // 0x28 '('
  {   290,   8,  29,  11,    2,  -22 },   // 0x29 ')'
  {   319,  13,  12,  15,    1,  -22 },   // 0x2A '*'
  {   339,  12,  13,  14,    1,  -15 },   // 0x2B '+'
  {   359,   4,   7,   8,    3,   -1 },   // 0x2C ','
  {   363,   9,   3,  12,    2,   -9 },   // 0x2D '-'
  {   367,   4,   4,   7,    2,   -3 },   // 0x2E '.'
  {   369,  13,  24,  15,    1,  -22 },   // 0x2F '/'
  {   408,  16,  22,  18,    1,  -21 },   // 0x30 '0'
  {   452,   9,  22,  13,    2,  -21 },   // 0x31 '1'
  {   477,  14,  22,  18,    2,  -21 },   // 0x32 '2'
  {   516,  13,  22,  18,    2,  -21 },   // 0x33 '3'
  {   552,  16,  22,  18,    1,  -21 },   // 0x34 '4'
  {   596,  14,  22,  18,    2,  -21 },   // 0x35 '5'
  {   635,  14,  22,  18,    2,  -21 },   // 0x36 '6'
  {   674,  16,  22,  18,    1,  -21 },   // 0x37 '7'
  {   718,  14,  22,  18,    2,  -21 },   // 0x38 '8'
  {   757,  14,  23,  18,    2,  -21 },   // 0x39 '9'
  {   798,   3,  13,   9,    3,  -14 },   // 0x3A ':'
  {   803,   5,  18,   9,    1,  -14 },   // 0x3B ';'
  {   815,   9,  12,  11,    0,  -14 },   // 0x3C '<'
  {   829,  11,  11,  15,    1,  -14 },   // 0x3D '='
  {   845,   9,  13,  11,    1,  -15 },   // 0x3E '>'
  {   860,  13,  22,  15,    1,  -20 },   // 0x3F '?'
  {   896,  23,  25,  27,    2,  -22 },   // 0x40 '@'
  {   968,  17,  22,  21,    2,  -21 },   // 0x41 'A'
  {  1015,  14,  23,  18,    3,  -21 },   // 0x42 'B'
  {  1056,  16,  22,  17,    1,  -21 },   // 0x43 'C'
  {  1100,  16,  22,  21,    3,  -21 },   // 0x44 'D'
  {  1144,  15,  22,  18,    2,  -21 },   // 0x45 'E'
  {  1186,  15,  22,  18,    2,  -21 },   // 0x46 'F'
  {  1228,  18,  22,  20,    1,  -21 },   // 0x47 'G'
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

const GFXfont __comic15pt7b PROGMEM = {
  (uint8_t  *)__comic15pt7bBitmaps,
  (GFXglyph *)__comic15pt7bGlyphs,
  0x20, 0x7E, 40
};

// Approx. 3929 bytes
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
void loop() {

  display.clearDisplay();
  pcswitch = digitalRead(localswitchPin);
  // pcswitch = 0 if pushed, 1 if released

  if (pcswitch == 1) {
    if (digitalRead(rfidChipAcceptPin) == 0) {
      display.clearDisplay();
      drawPcSuccessRfid();
      resetFontStyles();
      display.setCursor(24, 24);
      display.println("card detected");
      display.display();

      delay(1000);
      timestamp = 0;
    }
    if (digitalRead(rfidLockPcPin) == 0) {
      display.clearDisplay();
      drawPcLocked();
      resetFontStyles();
      display.setCursor(6, 24);
      display.println("card gone, pc locked");
      display.display();

      delay(1000);
      timestamp = 0;
    }

    if (frame > 80) frame = frame - 80;

    if (timestamp < 100) {

      display.clearDisplay();
      drawNanoSleep();
      display.display();

      timestamp++;
    }
    else {
      if (screensaver == 1) {
        doClock();
      }
      else if (screensaver == 2) {
        doCalendar();
      }
      else {
        if (x > 117 || x < 1) {
          goingright = !goingright;
        }
        if (y > 21  || y < 1) {
          goingup    = !goingup;
        }

        if (goingright == true) {
          x = x + 1;
        } else {
          x = x - 1;
        }

        if (goingup == true) {
          y = y + 1;
        } else {
          y = y - 1;
        }

        display.clearDisplay();
        display.drawBitmap(x, y, amogus[frame % 6], 10, 10, WHITE);
        frame++;
        display.display();
        delay(30);
      }
    }



  } else {
    if (digitalRead(keyLockPin) == 0) {
      Serial.println(F("pushed"));

      digitalWrite(pcswitchPin, HIGH);
      pcswitch = digitalRead(localswitchPin);
      while (pcswitch == 0) {
        display.clearDisplay();
        drawButtonPushedBig();
        display.display();
        delay(50);
        pcswitch = digitalRead(localswitchPin);
      }
      digitalWrite(pcswitchPin, LOW);
      commsIn = digitalRead(commsInPin);
      if (commsIn == 1) {
        Serial.println("audio not ready");
        // Not ready to play sound, show error message and continue
        frame = 0;
        while (frame < 7) {
          display.clearDisplay();
          drawNotReady(frame % 2);
          // display.drawBitmap(0, 0, notready[frame % 2], 128, 32, WHITE);
          display.display();
          delay(500);
          frame++;
        }
        frame = 0;
      } else {
        frame = 89;
        display.clearDisplay();
        drawContactingNano();
        display.display();
        digitalWrite(commsOutPin, HIGH);
        while (commsIn == 0) {
          if (frame % 89 == 0) {
            display.clearDisplay();
            drawContactingNano();
            display.display();
          } if (frame == 255) {
            Serial.print("request timed out");
            frame = 0;
            while (frame < 7) {
              display.clearDisplay();
              drawTimedOut(frame % 2);
              // display.drawBitmap(0, 0, notready[frame % 2], 128, 32, WHITE);
              display.display();
              delay(500);
              frame++;
            }
            return;
          }
          display.drawPixel((frame % 89) + 18, 13, BLACK);
          display.drawPixel((frame % 89) + 19, 13, WHITE);
          display.drawPixel((frame % 89) + 20, 13, WHITE);
          display.drawPixel((frame % 89) + 21, 13, WHITE);

          display.drawBitmap(59, 7, wait_shadow, 11, 11, BLACK);
          display.drawBitmap(59, 7, wait, 11, 11, WHITE);

          display.display();

          frame++;
          commsIn = digitalRead(commsInPin);
        }
        // connection established, playing sound...
        digitalWrite(commsOutPin, LOW);
      }
      delay(250);
      timestamp = 0;
    }
    else {
      display.clearDisplay();
      display.drawBitmap(54, 2, key, 21, 22, WHITE);
      resetFontStyles();
      display.setCursor(8, 24);
      display.println("unlock switch first");
      display.display();

      while (digitalRead(keyLockPin) == 0) {
      }
      delay(500);
      timestamp = 0;
    }
  }

}

void drawSplash() {
  display.clearDisplay();
  display.drawBitmap(8, 0, big_chester, 33, 32, WHITE);
  display.drawBitmap(41, 11, che, 82, 13, WHITE);
  display.display();
  delay(750);

  for (int i = 0; i < 7; i++) {

    display.clearDisplay();
    display.drawBitmap(8, 0, big_chester, 33, 32, WHITE);
    display.drawBitmap(48, 15 + i, edupraha_only, 70, 8, WHITE);
    display.fillRect(41, 11 - i, 82, 14, BLACK);
    display.drawBitmap(41, 11 - i, che, 82, 13, WHITE);
    display.display();
    delay(100);
  }

  delay(1000);
}

void doClock() {
  long rnMilis = milisAtStart + millis();
  long rnSecs = rnMilis / 1000;
  long rnMins = rnSecs / 60;
  long rnHours = rnMins / 60;

  rnMilis = rnMilis % 1000;
  rnSecs = rnSecs % 60;
  rnMins = rnMins % 60;
  rnHours = rnHours % 24;

  drawCenteredText(noToDD(rnHours) + ":" + noToDD(rnMins) + ":" + noToDD(rnSecs));
}

void doCalendar() {
  {
    long rnMilis = milisAtStart + millis();
    long rnSecs = rnMilis / 1000;
    long rnMins = rnSecs / 60;
    long rnHours = rnMins / 60;

    byte rnDays = dayAtStart + rnHours / 24;
    byte rnMonth = monthAtStart;
    int rnYear = yearAtStart;


    // Arduino nedokáže udržet přesnej čas o moc dýl než 50 dní, takže
    // se nemůže stát, že by tenhle forloop nestačil. I tak jsem pro
    // jistotu použil 3x loop, aby nebyla ani majinkatá šance.
    for (int i = 0; i < 3; i++) {
      if (rnDays > 28) {
        switch (rnMonth) {
          case 1:
          case 3:
          case 5:
          case 7:
          case 8:
          case 10:
            if (rnDays > 31) {
              rnDays = rnDays - 31;
              rnMonth++;
            }
            break;
          case 4:
          case 6:
          case 9:
          case 11:
            if (rnDays > 30) {
              rnDays = rnDays - 30;
              rnMonth++;
            }
            break;
          case 2:
            if (rnDays > 28) {
              rnDays = rnDays - 28;
              rnMonth++;
            }
            break;
          case 12:
            if (rnDays > 31) {
              rnDays = rnDays - 31;
              rnMonth = 1;
              rnYear++;
            }
            break;
        }
      }
    }

    rnMilis = rnMilis % 1000;
    rnSecs = rnSecs % 60;
    rnMins = rnMins % 60;
    rnHours = rnHours % 24;

    draw11pCenteredText(noToDD(rnDays) + "." + noToDD(rnMonth) + "." + rnYear);
  }
}

String noToDD(long i) { // Double Digits
  if (i < 10)
    return "0" + String(i);
  else
    return String(i);
}

String noToTD(long i) { // Triple Digits
  if (i < 10)
    return "00" + String(i);
  else if (i < 100)
    return "0" + String(i);
  else
    return String(i);
}

void drawCenteredText(String str, bool forcePrintVerbose) {
  unsigned int width;
  unsigned int height;
  int curX;
  int curY;

  display.clearDisplay();
  display.setTextColor(SSD1306_WHITE);
  display.setFont(&__comic15pt7b);
  display.setTextSize(1);
  display.getTextBounds(str, 0, 0, &curX, &curY, &width, &height);  // na pozicích curX a curY to vrací souřadnice spodního levýho rohu, což nepotřebuju, ale ty pozice musej bejt vyplněný, tak používám něco, co pak hned přepíšu

  curX = 63 - (width / 2);
  curY = 15 + (height / 2) ;

  if (verboseReportCount % 250 == 0 || forcePrintVerbose)
    Serial.println(str);
  // Serial.println(str + ", " + String(width) + ", " + String(height) + ", " + String(curX) + ", " + String(curY));

  verboseReportCount++;

  if (verboseReportCount > 250) {
    verboseReportCount = verboseReportCount - 250;
  }

  display.setCursor(curX, curY);
  display.println(str);
  display.display();

  display.setFont();
}

void drawCenteredText(String str) {
  drawCenteredText(str, false);
}



void draw11pCenteredText(String str, bool forcePrintVerbose) {
  unsigned int width;
  unsigned int height;
  int curX;
  int curY;

  display.clearDisplay();
  display.setTextColor(SSD1306_WHITE);
  display.setFont(&__comic11pt7b);
  display.getTextBounds(str, 0, 0, &curX, &curY, &width, &height);  // na pozicích curX a curY to vrací souřadnice spodního levýho rohu, což nepotřebuju, ale ty pozice musej bejt vyplněný, tak používám něco, co pak hned přepíšu

  curX = 63 - (width / 2) ;
  curY = 15 + (height / 2)  ;

  if (verboseReportCount % 250 == 0 || forcePrintVerbose)
    Serial.println(str);
  // Serial.println(str + ", " + String(width) + ", " + String(height) + ", " + String(curX) + ", " + String(curY));

  verboseReportCount++;

  if (verboseReportCount > 250) {
    verboseReportCount = verboseReportCount - 250;
  }

  display.setCursor(curX, curY);
  display.println(str);
  display.display();

  display.setFont();
}
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

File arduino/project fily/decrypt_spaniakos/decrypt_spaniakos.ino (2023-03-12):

#include <CzechKeyboard_QWERTZ.h>

#include <AES.h>
#include <AES_config.h>
#include "base64.hpp"
#include "EasyMFRC522.h"


AES aes;

EasyMFRC522 rfid(10, 9);

// !!! DŮLEŽITÉ !!!
// Šifrovací klíč i inicializační vektor níže se musí
// shodovat s těmi, které byly použity k šifrování hesla.

// Šifrovací klíč           "Sem je to AES128"sem 192"sem 256"
byte *key = (unsigned char*)"4428472B4B625065";

// Inicializační vektor
unsigned long long int my_iv = 22176790;

int padedLength = 32; // vždycky šifrovat do dvou segmentů


void setup() {
  Serial.begin (9600);
  while (!Serial) {
    ; // wait for serial port to connect. Needed for Leonardo only
  }
  delay(500);
  rfid.init();
  Keyboard.begin();

  pinMode(11, OUTPUT);  // card accepted
  pinMode(12, OUTPUT);  // card removed, pc locked

  Serial.println("RFID module");
}

void loop() {
  String y = key;
  if (y.length() == 16) {
    prectiADesifruj(128);
  }
  else if (y.length() == 24) {
    prectiADesifruj(192);
  }
  else if (y.length() == 32) {
    prectiADesifruj(256);
  }
  else {
    Serial.print("ZVOLENA NEPLATNÁ DÉLKA KLÍČE (");
    Serial.print(sizeof(key));
    Serial.println(")");
    Serial.println("PODPOROVANÉ DÉLKY KLÍČE JSOU:");
    Serial.println("16 ZNAKŮ PRO AES128 (VYSOKÁ ÚROVEŇ ZABEZPEČENÍ)");
    Serial.println("24 ZNAKŮ PRO AES192 (VELMI VYSOKÁ ÚROVEŇ ZABEZPEČENÍ)");
    Serial.println("32 ZNAKŮ PRO AES256 (EXTRÉMNĚ VYSOKÁ ÚROVEŇ ZABEZPEČENÍ)");

    while (true) {
    }

  }
}

void prectiADesifruj (int bits)
{
  aes.iv_inc();
  byte iv [N_BLOCK] ;
  byte cipher [padedLength] ;
  byte check [padedLength] ;

  char pass64[64] = {0};
  char passLen[4] = {0};
  char logOffPref[5] = {0};

  String s;
  int block = 0;
  int newBlock;

  byte tagID[4] = {0};

  Serial.println();
  Serial.println(F("READY TO READ"));

  bool success = false;
  do {
    // returns true if a Mifare tag is detected
    success = rfid.detectTag(tagID);
    delay(50); //0.05s
  } while (!success);

  digitalWrite(11, HIGH);
  delay(100); // Ensures the chip is close enough

  Serial.println(F("TAG DETECTED!"));
  Serial.print(F("READING PASSWORD... "));
  block = rfid.readFile(1, "Pass", (byte*)pass64, 64);
  digitalWrite(11, LOW);
  if (block >= 0) {
    Serial.println(F("SUCCESS"));
    s = pass64;
    Serial.println(s);

    Serial.print(F("READING LENGTH... "));
    block = rfid.readFile(40, "PLen", (byte*)passLen, 64);
    if (block >= 0) {
      Serial.println(F("SUCCESS"));
      s = passLen;
      Serial.println(s);

      Serial.print(F("READING LOGOFF PREFERENCE... "));
      newBlock = rfid.readFile(50, "LogOff", (byte*)logOffPref, 64);
      if (newBlock >= 0) {
        Serial.println(F("SUCCESS"));
        s = logOffPref;
        Serial.println(s);
      }
      else {
        Serial.print("READING FAILED");
        Serial.println(newBlock);
      }

    }
    else {
      Serial.print("READING FAILED");
      Serial.println(block);
    }

    decode_base64(pass64, cipher);

    aes.set_IV(my_iv);
    aes.get_IV(iv);
    aes.do_aes_decrypt(cipher, padedLength, check, key, bits, iv);

    s = passLen;

    Serial.println(s.toInt());
    String result = check;
    result = result.substring(0, s.toInt());
    Serial.println(result);
    Keyboard.print(result);
    Keyboard.flush();
  } else {
    Serial.print("READING FAILED ");
    Serial.println(block);
  }

  s = logOffPref;
  if (s.charAt(0) == 't') {
    String s1;

    rfid.unselectMifareTag(true);
    delay(50);

    byte newTagID[4] = {0};
    byte badReads = 0;

    do {
      for (byte IDsegment : newTagID) {
        IDsegment = 0;
      }

      success = rfid.detectTag(newTagID);

      if (success) {
        for (byte i = 2; i < 4; i++) {
          if (tagID[i] != newTagID[i]) {
            success = false;
            break;
          }
        }

        Serial.print("Old tag ID: ");
        for (byte i = 2; i < 4; i++) {
          Serial.print(String(tagID[i]));
          Serial.print(", ");
        }
        Serial.println();

        Serial.print("New tag ID: ");
        for (byte i = 2; i < 4; i++) {
          Serial.print(String(newTagID[i]));
          Serial.print(", ");
        }
        Serial.println();
      }

      if (success) {
        Serial.println("Good read!");
        badReads = 0;
      } else {
        Serial.print("Bad read: ");
        badReads++;
        Serial.println(badReads);
      }

      rfid.unselectMifareTag(true);
      delay(100);
    } while (badReads < 10);


    Serial.print("Old tag ID: ");
    for (byte i = 2; i < 4; i++) {
      Serial.print(String(tagID[i]));
      Serial.print(", ");
    }
    Serial.println();

    Serial.print("New tag ID: ");
    for (byte i = 2; i < 4; i++) {
      Serial.print(String(newTagID[i]));
      Serial.print(", ");
    }
    Serial.println();

    Keyboard.press(KEY_LEFT_GUI);
    Keyboard.press('l');
    digitalWrite(12, HIGH);
    delay(100);
    Keyboard.releaseAll();
    digitalWrite(12, LOW);
  }

  rfid.unselectMifareTag();
  delay(3000);
}

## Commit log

2022-11-17 optimalizace power button sketche + animace
2022-11-23 dev printy na displej nahrazeny gfx, python error fix
    [enhanced-power-button-config.txt]
2022-11-25 reorganizace audia, menší práce na práci a button sprity
2022-12-01 Bugfix: 'contacting nano' even when not
    drawNanoAndNano() dělalo to, co by měla dělat tehdy neexistující funkce drawContactingNano()
    [custom_power_button.ino]
2022-12-10 optimalizace pythonu a bugfixy
    [main.py]
2022-12-10 optimalizace power button sketche a kus práce(?)
2023-02-03 malej tweak timingu a rozvržení kódu v power buttonu
2023-02-04 sound upgrade
    change in how the arduino detects playable files, naming conventions
    also added few more sounds to the mix
2023-02-07 přepythonování
    [enhanced-power-button-config.txt]
2023-02-07 remove unused printf
2023-02-09 gigacommit
    Kompletní debordelizace a přetřídění
    Smazání zbytečnýho bogusu
    Oprava agresivní komprese Word filů (práce teď má >300MB a nevejde se na github. dostupná bude jen z google drivu)
    [concept art.blend]
2023-03-05 Finální commit včetně malý .pdf verze maturitní práce
    [concept art.blend, panel krabičky.stl, poklop krabičky.stl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]
2023-03-11 Create enhanced-power-button-log (ntb).txt
2023-03-22 finální verze před odevzdánim
    [slovník pojmů.xlsx]

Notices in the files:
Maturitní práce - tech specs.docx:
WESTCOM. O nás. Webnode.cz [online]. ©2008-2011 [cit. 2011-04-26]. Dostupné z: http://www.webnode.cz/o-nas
